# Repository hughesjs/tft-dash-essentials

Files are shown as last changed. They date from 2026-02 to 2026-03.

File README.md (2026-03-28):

# TFT Dash

A motorcycle dashboard replacement system. An Arduino-based interface board reads sensor signals from the bike — speed, RPM, coolant temperature, fuel level, battery voltage, indicators, and more — and streams data over USB serial to a Raspberry Pi, which renders a real-time graphical dashboard using SDL3.

## System Architecture

```
Phone App (BLE) ──> Arduino Firmware ──> USB Serial ──> Raspberry Pi Display
                    (ATMega32u4)          115200 bps     (SDL3, 1024x600)
                                                               |
                                                    TPMS Sensors (USB Serial)
```

The firmware outputs comma-delimited messages at 115200 bps. The display application deserialises these into dashboard state and renders at 60 fps. A separate TPMS receiver provides tyre pressure data via a second serial connection.

## Display Software Architecture

```
main.c (init, event loop, rendering)
  ├── draw.h          shared rendering state and drawing primitives (in progress)
  ├── dashboard_anims.h/c   animation instances and data tables
  │   └── animation.h/c     generic data-driven animation engine
  ├── sensor_feed.h/c       firmware serial data + comms staleness tracking
  ├── tpms_feed.h/c         tyre pressure serial data
  ├── parser.h/c             serial message deserialisation
  ├── assets.h/c             PNG texture management (stb_image)
  └── menu.h/c               menu screen data tables
```

Pure C23 codebase. Three threads: main (render + animation ticking), sensor feed (firmware serial), and TPMS feed (tyre pressure serial). 62 tests across 6 suites.

## Repository Structure

| Directory | Description |
|---|---|
| `display/` | Display application (C23/SDL3) for Raspberry Pi |
| `firmware/` | Arduino firmware for the sensor interface board (ATMega32u4) |
| `hardware/` | EAGLE schematic/board files for Gen4 PCB + 3D-printable enclosure STLs |
| `simulator/` | .NET/Avalonia desktop simulator for development without hardware |
| `buildroot-tftdash/` | Buildroot external tree for building the Pi SD card image |
| `docs/` | Protocol specs, signal reverse engineering notes, update system design |

## Quick Start

```bash
# Build the display application (requires Zig 0.15+)
make display

# Run all tests
make test

# Build the firmware (requires arduino-cli)
make firmware

# Build the simulator (requires .NET 10)
make simulator

# Full SD card image (firmware + display cross-compile + Buildroot)
make

# See all targets
make help
```

### Bike Model Selection

Uncomment one define at the top of `firmware/firmware.ino`:

- `#define BIKE_FZS1000` — Yamaha FZS1000 Fazer
- `#define BIKE_FZS600` — Yamaha FZS600 Fazer

This controls gear ratios, primary drive ratio, wheel diameter, and RPM calibration.

## Features

- Real-time speed, RPM, coolant temperature, battery voltage, and fuel level
- Gear position indicator (calculated from sprocket ratios)
- Turn indicator, high beam, neutral, and oil warning lights
- TPMS (tyre pressure monitoring) with two hardware variants
- Navigation overlay with turn-by-turn directions
- 9 colour themes with automatic day/night switching
- On-screen menu system for configuration
- NO COMMS warning when serial data goes stale
- Data-driven animation system (startup sequence, RPM effects, transitions)
- A/B rootfs update system for atomic SD card updates

## Documentation

See `docs/` for detailed documentation:

- **`SERIAL-PROTOCOL.md`** — Complete serial protocol specification
- **`signal-reverse-engineering.md`** — Electrical signal details and calibration constants
- **`ab-update-plan.md`** — A/B rootfs update system design
- **`ota-update-plan.md`** — Over-the-air WiFi update architecture (planned)

## Licence

2018-2025 TFTDashProject / Danny Draper.

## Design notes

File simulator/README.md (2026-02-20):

# TFT Dash Simulator

A cross-platform desktop simulator for the TFT Dash motorcycle dashboard system, built with Avalonia UI.

## Features

- **Modern Desktop UI**: Built with Avalonia 11.2 for native look and feel on Linux, macOS, and Windows
- **Dark Theme**: VS Code Dark+ colour scheme for comfortable viewing
- **Live Preview**: Real-time serial protocol message generation with parsed field display
- **Interactive Controls**: All 36 dashboard data fields editable via NumericUpDown and CheckBox controls
- **Preset Scenarios**: Quick-access buttons for common riding states (Idle, Cruising, High Speed, Low Fuel)
- **Keyboard Shortcuts**: F1-F4 for presets, Esc to exit
- **Pipe Output**: Optional FIFO pipe output at 10 Hz for integration with TFT Dash display software

## Building

```bash
dotnet build
```

## Running

Normal mode (GUI only):
```bash
dotnet run --project src/TftDashSimulator/TftDashSimulator.csproj
```

With pipe output (GUI + /tmp/tft-dash-pipe at 10 Hz):
```bash
dotnet run --project src/TftDashSimulator/TftDashSimulator.csproj -- --pipe
```

## Testing

```bash
dotnet test
```

## Project Structure

- `src/TftDashSimulator/` - Main application
  - `Core/` - Core logic and serial protocol handling (UI-agnostic)
  - `Views/` - Avalonia AXAML views (MainWindow, ControlsView, PreviewView)
  - `ViewModels/` - MVVM ViewModels
  - `Converters/` - Value converters for data binding
  - `Styles/` - Dark theme AXAML styles
- `tests/TftDashSimulator.Tests/` - Unit tests

## Architecture

The simulator uses the MVVM pattern:
- **DashboardState** (Model): Thread-safe state with INotifyPropertyChanged
- **MainViewModel**: Exposes DashboardState and preset commands
- **Views**: Avalonia UserControls with two-way data binding
- **MessageGenerator**: Converts DashboardState to TFT Dash serial protocol format
- **PipeWriter**: Background thread writing to FIFO pipe at 10 Hz (when --pipe flag is used)

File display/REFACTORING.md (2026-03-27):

# TFT Dash Refactoring Progress

## Completed

### Parser extraction
- Extracted message parsing from `testsdl.cpp` into `parser.h/c`
- Data-driven field descriptor tables instead of if-ladders
- Tokenisation via `strsep` (C23 + `_GNU_SOURCE`)
- Comprehensive test suite in `test_parser.c` (10 tests, all passing)
- `zig build test` to run

### Asset manager extraction
- Standalone `assets.h/c` module for themed BMP loading
- Two-key hash map lookup: `(theme, asset_name)` → `SDL_Texture*`
- FNV-1a hashing, open addressing with linear probing, auto-resize at 70% load
- `asset_store_load_theme()` scans directories via `opendir`/`readdir`
- Test suite in `test_assets.c` (7 tests, all passing)
- `zig build test` runs both parser and asset tests

### Asset store integration into testsdl.cpp
- Replaced 143 global variables (72 `SDL_Surface*` + 71 `SDL_Texture*`) with 2 (`g_assets` + `g_current_theme`)
- Deleted `load_surface()`, `load_surfaces()`, and `init_textures()` (~1000 lines of boilerplate)
- All 9 themes loaded upfront at startup — no per-switch disk I/O
- Theme switching is now a string assignment instead of full surface reload + texture recreation
- `tex("Name.bmp")` helper for current-theme lookups, `tex_from("theme", "Name.bmp")` for fixed-theme
- Default-only assets (odometer setup, theme arrows) use `tex_from("default", ...)`
- Per-theme thumbnails use `tex_from("green", "greenthumb.bmp")` etc.
- ~1250 lines deleted, ~40 lines added

### Drawing function deduplication
- Replaced 7 near-identical `draw_*_string()` functions (~270 lines) with one `draw_glyph_string()` renderer (~20 lines)
- Data-driven `glyph_font` struct captures all differences: texture name, sprite atlas coords, glyph character set, case-insensitive matching, inter-glyph spacing, whitespace handling, clipping, and per-glyph y-offsets
- 8 font descriptors defined as static const: `FONT_SMALL_GREY`, `FONT_SMALL_BLUE`, `FONT_MEDIUM`, `FONT_LARGE`, `FONT_NAV_LARGE`, `FONT_NAV_SMALL`, `FONT_NAV_DIGITS`
- All existing function names kept as one-line wrappers (86 call sites untouched)
- `draw_speed_digit` left as-is (renders to pre-positioned destination rects, not a flowing string)

### snake_case naming convention
- All functions, globals, locals, struct types and members converted to snake_case
- Constants remain UPPER_CASE (already correct)

### Zig build system
- Replaced manual g++ invocations with `build.zig`
- Builds main app, parser tests, and handles asset copying
- Cross-compilation support for aarch64

## Display-side refactoring opportunities

### Sensor feed extraction
- Extracted serial connection, byte framing, and message parsing into `sensor_feed.h/c`
- Opaque `sensor_feed` struct — consumers get `const` pointers, can't write state
- Replaced ~50 global variables with `dash->`, `menu->`, `nav->` struct field access
- Deleted ~1400 lines from testsdl.cpp: `connect_interface()`, `pollInterface()`, `unpack_message()`, `unpack_menu_message()`, `unpack_nav_message()`, `choice()`, `select()`, test scenario functions
- 9 integration tests via named pipes in `test_sensor_feed.c`
- testsdl.cpp reduced from ~4400 to ~3070 lines

### Next: further extractions
The same pattern can be applied to:

1. **Extract the menu system** — `draw_menu()` (~500 lines of nested ifs) takes explicit input/output.
2. **Extract TPMS** — small, self-contained, same pattern.
3. **What remains in testsdl.cpp** is `main()`, the render loop, and drawing helpers — a thin orchestrator.

### Smaller wins (do whenever convenient)

1. ~~**Texture loading boilerplate**~~ — **Done.** Replaced by asset store integration.

2. ~~**Theme descriptor table**~~ — **Done.** `THEME_NAMES[]` array + `theme_name_from_id()` replaces all `if (theme == X)` ladders.

3. ~~**Nav symbol lookup table**~~ — **Done.** Replaced 17 strcmp chains with `nav_symbol_entry` lookup table + `nav_icon` enum.

4. ~~**Warning badge priority**~~ — **Done.** Replaced nested if/else staircase with `resolve_warning()` lambda returning a `warning_badge` struct. Priority order is now a flat list of early-returns.

5. **Nav distance protocol** — The phone app sends yards AND miles as separate fields, and the display picks which to show based on `nav_yards <= 300`. This split of responsibility is daft — the phone app knows the distance, it should send one value and let the display format it. Requires a phone app + protocol change.

## Firmware architectural change (future option)

### Current state

The firmware handles both signal acquisition AND application logic:
- Reads sensors, averages, converts to meaningful units
- Manages the entire menu state machine (which menu, which digit being edited, cycling values)
- Stores all settings in EEPROM (theme, units, sprockets, fan temp, TPMS, etc.)
- Controls the fan relay
- Tracks odometer/trips and persists to EEPROM
- Manages RTC

The display just renders whatever state the firmware sends. The protocol is one-directional (firmware to display).

### Proposal: move menu logic to the display

Make the firmware a sensor bridge. It reads hardware, outputs values, and accepts setting commands from the display.

**Stays on firmware (hardware-dependent):**
- Sensor reading, averaging, signal processing
- Fan relay control (safety-critical — must work if display crashes)
- Odometer/trip persistence in EEPROM (SD card too fragile for frequent writes on a motorcycle)
- RTC read/write
- Speed correction (must happen before odometer accumulation)

**Moves to display:**
- Menu state machine and navigation
- Theme/unit preferences (become Pi-side config, possibly a file)
- All menu digit editing state (odo digits, time digits, speed correction digits)

**New protocol:**

```
Firmware -> Display (sensor data only):
  {,speed,rpm,coolant,batt,fuel,neutral,oil,highbeam,left,right,
   gear,ambient_temp,hour,minute,odo,trip1,trip2,oil_press,oil_temp,
   fan_state,button_option,button_select,}

Display -> Firmware (commands):
  CMD:RESET_TRIP1
  CMD:RESET_TRIP2
  CMD:SET_SPD_CORRECT:-2.5
  CMD:SET_TIME:14:23
  CMD:SET_SPROCKET_FRONT:15
  CMD:SET_SPROCKET_REAR:44
  CMD:SET_FAN_TEMP:95
  CMD:SET_FAN_MODE:2
  CMD:SET_GEAR_INTERVAL:200
  CMD:SAVE_ODO
```

**Benefits:**
- Firmware becomes much simpler — no menu state machine, no digit editor state
- Serial protocol shrinks — no more sending 6 odo digits, 4 time digits, etc.
- Adding/changing menus only requires display changes
- Display-only settings (theme, units) don't round-trip through the firmware
- Button events are raw — display decides what they mean in context

**Costs:**
- Bidirectional serial (trivial — `Serial.read()` on Arduino, `write()` on Pi)
- Settings persistence needs thought — EEPROM for hardware settings, file for display settings
- If display is down, buttons do nothing (but they're useless without a screen anyway)

**Implementation path:**
1. Add `Serial.read()` command handler to firmware
2. Strip menu state machine from firmware
3. Implement menu logic on display side
4. Simplify serial protocol
5. Add display-side config file for theme/units/layout

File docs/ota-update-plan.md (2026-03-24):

# OTA Update System — WiFi AP Mode

Design for wireless update delivery without USB sticks.

## Architecture

The Pi temporarily becomes a WiFi access point. A phone app connects and pushes the update directly. BLE (or a physical button combo) triggers update mode.

```
Phone App                    Arduino (BLE)              Pi
─────────                    ─────────────              ──
1. Tap "Update"
2. Send BLE ──────────────> Relay ──────────────> Start hostapd AP
   "START_UPDATE"                                  "TFTDash" network
                                                   Start HTTP server
                                                   on 192.168.4.1:8080

3. Join "TFTDash" network
   (iOS: NEHotspotConfiguration
    with system dialog)

4. POST update zip ─────── WiFi direct to Pi ───> Receive, extract,
   to 192.168.4.1:8080                            apply update

5. Pi responds 200 OK ──── WiFi ────────────────> Tear down AP
                                                   Restart dash
6. Phone auto-rejoins
   previous network
```

## Why This Approach

### BLE alone is too slow
The update package is ~10MB zipped, 330MB uncompressed. BLE tops out at 10-30 KB/s. Even the compressed package would take 5-15 minutes. The full BMP set uncompressed would take hours. The ATMega32u4 only has 2.5KB of RAM — it can't buffer or relay large transfers.

### Pi as AP avoids phone hotspot dependency
iOS has no public API to enable Personal Hotspot programmatically (`NEHotspotConfiguration` only joins existing networks, it can't create one). A Pi-hosted AP works identically on iOS and Android with no manual steps.

### Fixed known IP
The Pi is always 192.168.4.1 as the AP gateway. No mDNS discovery, no DHCP lease parsing, no platform-specific gateway addresses.

### BLE only carries control messages
"Start update mode" and "disconnect" — tiny messages that the existing BLE relay through the Arduino handles already. No new BLE protocol needed.

## Implementation Plan

### 1. Pi-Side Update Daemon

A small service/script that:

1. **Listens for update trigger** — either:
   - BLE command relayed via serial (watches for `<UPD:START%>` in the serial stream)
   - Physical button combo (hold option + select for 5 seconds) for garage use without a phone
2. **Starts WiFi AP** — `hostapd` + `dnsmasq` to create "TFTDash" network on 192.168.4.1
3. **Runs HTTP server** on port 8080 accepting POST to `/update`
4. **Receives and applies update** — validate zip, extract to staging area, copy binary + assets into place, optionally flash firmware hex via avrdude
5. **Tears down AP** and restarts the dashboard

Could be ~50 lines of bash wrapping a small HTTP receiver (e.g. Python one-liner or a tiny C program).

### 2. Firmware Changes

- New BLE message type: `<UPD:START%>` to trigger update mode
- Arduino relays to Pi via existing serial passthrough — the firmware already passes all BLE messages through, so this may need no firmware changes at all beyond the phone app sending the right string

### 3. Phone App

- "Update Dash" button that bundles the current update zip
- Sends BLE `START_UPDATE` command to the Arduino
- Uses `NEHotspotConfiguration` (iOS) / standard WiFi API (Android) to join "TFTDash" network — iOS shows one system confirmation dialog
- POSTs zip to `http://192.168.4.1:8080/update`
- Shows progress bar during upload
- Handles success/failure response from Pi
- On completion, phone auto-rejoins its previous network

### 4. Pi Requirements

- `hostapd` and `dnsmasq` packages installed on the Pi SD card image
- WiFi hardware (Pi 3 has built-in, but it is **currently disabled** via `dtoverlay=pi3-disable-wifi` in `/boot/config.txt` — this needs removed)
- Bluetooth is also disabled (`dtoverlay=pi3-disable-bt`) — can stay disabled since BLE goes through the Arduino, not the Pi
- Pre-configured `hostapd.conf` for the "TFTDash" AP
- The update daemon installed as a systemd service or integrated into `updatetft.sh`
- Root filesystem is read-only — daemon must remount rw before applying updates (existing script already does this)

## Current Update Mechanism (USB A/B)

The A/B rootfs update system handles USB-based updates — see `docs/ab-update-plan.md`. OTA via WiFi AP would be an additional delivery path using the same rootfs image format.

## TODO

- [ ] Implement Pi-side update daemon (hostapd AP + HTTP receiver)
- [ ] Add `<UPD:START%>` BLE message handling (may be zero firmware work)
- [ ] Phone app: BLE trigger + WiFi join + HTTP upload

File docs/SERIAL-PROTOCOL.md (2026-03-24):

# TFT Dash Serial Protocol

This document describes the serial communication protocols used by the TFT Dash system. There are three independent serial interfaces:

1. **Main interface** - Firmware to Display (USB serial)
2. **TPMS interface** - Tyre Pressure Monitoring System sensors to Display (separate USB serial)
3. **Navigation interface** - Phone to Firmware via BLE module on the Arduino (passed through to the Display embedded in the main interface output)

---

## 1. Main Interface (Firmware to Display)

**Connection:** USB serial over `/dev/ttyACM0` or `/dev/ttyACM1` (Linux) / `/dev/cu.usbmodem*` or `/dev/cu.usbserial-*` (macOS)

**Baud rate:** 115200

**Serial config:** 8N1, no flow control

**Direction:** Firmware sends continuously; display receives and parses.

The firmware outputs one of two message types on each loop iteration, depending on whether the user is in the main dashboard view or navigating the on-screen menu.

### 1.1 Live Data Message

Sent when the dashboard is in normal (non-menu) mode. Contains real-time sensor readings.

**Format:** `{,field1,field2,...,fieldN,}`

- Starts with `{`
- Fields are comma-delimited
- Ends with `}`
- Valid messages are between 90 and 400 characters in length

| Field index | Field | Type | Description |
|---|---|---|---|
| 0 | `{` | char | Start marker |
| 1 | speed | unsigned int | Current speed (in user's chosen unit: MPH or KM/H) |
| 2 | rpm | unsigned int | Engine RPM |
| 3 | coolant | int | Coolant temperature (averaged) |
| 4 | battery | float | Battery voltage (e.g. `12.5`) |
| 5 | hour | int | Current hour (0-23) from RTC |
| 6 | minute | int | Current minute (0-59) from RTC |
| 7 | fuel | int | Fuel float sensor value (raw integer) |
| 8 | neutral | int | Neutral light (1 = engaged, 0 = off) |
| 9 | oil | int | Oil level warning (1 = warning, 0 = ok) |
| 10 | highbeam | int | High beam indicator (1 = on, 0 = off) |
| 11 | left | int | Left indicator (1 = on, 0 = off) |
| 12 | right | int | Right indicator (1 = on, 0 = off) |
| 13 | menustate | int | Current menu state (`menulevel + choicestate`; 0 = main dashboard) |
| 14 | infomode | int | Info panel display mode |
| 15 | trip1 | float | Trip 1 distance (in user's chosen unit) |
| 16 | trip2 | float | Trip 2 distance (in user's chosen unit) |
| 17 | odo | float | Odometer reading (in user's chosen unit) |
| 18 | km | int | Unit mode (1 = kilometres, 0 = miles) |
| 19 | speedcorrection | float | Speed correction factor |
| 20 | theme | int | Current display theme ID |
| 21 | ambient | int | Ambient temperature (averaged) |
| 22 | gear | int | Current gear (calculated from sprocket ratios) |
| 23 | mpg | int | Miles per gallon |
| 24 | range | int | Estimated range remaining |
| 25 | maxspeed | unsigned int | Maximum speed recorded this trip (in user's chosen unit) |
| 26 | triptimehour | int | Trip time hours |
| 27 | triptimemin | int | Trip time minutes |
| 28 | oilpressavail | int | Oil pressure hardware available (1 = yes, 0 = no). Always 0 on Gen4 boards. |
| 29 | oilpress | int | Oil pressure sensor reading (averaged). Always 0 on Gen4 boards. |
| 30 | oiltemp | int | Oil temperature sensor reading (averaged). Always 0 on Gen4 boards. |
| 31 | fahrenheit | int | Temperature unit (1 = Fahrenheit, 0 = Celsius) |
| 32 | bar | int | Pressure unit (1 = Bar, 0 = PSI) |
| 33 | frontsensor | int | TPMS front sensor ID |
| 34 | rearsensor | int | TPMS rear sensor ID |
| 35 | frontpressurelow | int | Front tyre low pressure threshold |
| 36 | rearpressurelow | int | Rear tyre low pressure threshold |
| 37 | nav | string | Navigation message from phone via BLE (see section 3). Empty if no navigation active. |
| *end* | `}` | char | End marker |

**Example:**
```
{,78,5200,89,12.5,14,35,477,0,1,0,0,0,0,0,12.5,24.8,1234.5,0,1.0,3,22,4,45,120,78,1,35,0,0,0,0,0,1,2,30,28,,}
```

### 1.2 Menu Data Message

Sent when the user is navigating the on-screen menu system (i.e. `menulevel + choicestate != 0`). Contains current menu state and all configurable settings.

**Format:** `[,field1,field2,...,fieldN,]`

- Starts with `[`
- Fields are comma-delimited
- Ends with `]`
- Valid messages are between 80 and 100 characters in length

| Field index | Field | Type | Description |
|---|---|---|---|
| 0 | `[` | char | Start marker |
| 1 | menustate | int | Current menu state (`menulevel + choicestate`) |
| 2 | ododigit1 | int | Odometer setup digit 1 |
| 3 | ododigit2 | int | Odometer setup digit 2 |
| 4 | ododigit3 | int | Odometer setup digit 3 |
| 5 | ododigit4 | int | Odometer setup digit 4 |
| 6 | ododigit5 | int | Odometer setup digit 5 |
| 7 | ododigit6 | int | Odometer setup digit 6 |
| 8 | odo2digit1 | int | Odometer confirmation digit 1 |
| 9 | odo2digit2 | int | Odometer confirmation digit 2 |
| 10 | odo2digit3 | int | Odometer confirmation digit 3 |
| 11 | odo2digit4 | int | Odometer confirmation digit 4 |
| 12 | odo2digit5 | int | Odometer confirmation digit 5 |
| 13 | odo2digit6 | int | Odometer confirmation digit 6 |
| 14 | odoerror | int | Odometer error state |
| 15 | settimedigit0 | int | Set time digit 0 (tens of hours) |
| 16 | settimedigit1 | int | Set time digit 1 (units of hours) |
| 17 | settimedigit2 | int | Set time digit 2 (tens of minutes) |
| 18 | settimedigit3 | int | Set time digit 3 (units of minutes) |
| 19 | spcdigit0 | int | Speed correction sign/digit 0 (+ or -) |
| 20 | spcdigit1 | int | Speed correction digit 1 |
| 21 | spcdigit2 | int | Speed correction digit 2 |
| 22 | spcdigit3 | int | Speed correction digit 3 |
| 23 | frontsprocket | int | Front sprocket tooth count |
| 24 | rearsprocket | int | Rear sprocket tooth count |
| 25 | coolantfantemp | int | Coolant fan activation temperature |
| 26 | km | int | Using kilometres (1 = km, 0 = miles) |
| 27 | fh | int | Using Fahrenheit (1 = Fahrenheit, 0 = Celsius) |
| 28 | bar | int | Using Bar (1 = Bar, 0 = PSI) |
| 29 | frontsensor | int | TPMS front sensor ID |
| 30 | rearsensor | int | TPMS rear sensor ID |
| 31 | frontpressurelow | int | Front tyre low pressure threshold |
| 32 | rearpressurelow | int | Rear tyre low pressure threshold |
| 33 | controllayout | int | Control button layout |
| 34 | daytheme | int | Day theme ID |
| 35 | nighttheme | int | Night theme ID |
| 36 | currentlightlevel | int | Current ambient light sensor reading |
| 37 | lightswitchvalue | int | Light level threshold for day/night switching |
| 38 | fanneutraloption | int | Fan neutral mode option in coolant fan setup |
| 39 | gearratiointerval | int | Gear ratio update interval setting |
| *end* | `]` | char | End marker |

### 1.3 Menu State Constants

Menu states are encoded as `menulevel + choicestate`. The major menu category is a single digit, and sub-options are encoded as `category * 100 + offset`:

| Constant | Value | Description |
|---|---|---|
| `MAINDASHBOARD` | 0 | Normal dashboard view (live data sent) |
| `RESETTRIP1` | 1 | Reset Trip 1 |
| `RESETTRIP2` | 2 | Reset Trip 2 |
| `CONTROLSETUP` | 3 | Control layout setup |
| `CONTROLLAYOUT1` | 301 | Control layout option 1 |
| `CONTROLLAYOUT2` | 302 | Control layout option 2 |
| `SETUNITS` | 4 | Unit selection menu |
| `SETUNITSMILES` | 401 | Select miles |
| `SETUNITSKM` | 402 | Select kilometres |
| `SETUNITSCELCIUS` | 403 | Select Celsius |
| `SETUNITSFARENHEIT` | 404 | Select Fahrenheit |
| `SETUNITSPSI` | 405 | Select PSI |
| `SETUNITSBAR` | 406 | Select Bar |
| `SETTIME` | 5 | Set time menu |
| `SETTIMEDIGIT1-4` | 501-504 | Individual time digits |
| `AMBIENTLIGHTSETUP` | 6 | Ambient light setup |
| `DAYTHEMEPLUS/MINUS` | 601-602 | Day theme selection |
| `NIGHTTHEMEPLUS/MINUS` | 603-604 | Night theme selection |
| `LIGHTLEVELPLUS/MINUS` | 605-606 | Light level threshold |
| `SPEEDCORRECTIONMENU` | 7 | Speed correction |
| `SETDISPLAYTHEME` | 8 | Theme selection |
| `GEARINDICATORSETUP` | 9 | Gear indicator / sprocket setup |
| `COOLANTFANSETUP` | 10 | Coolant fan temperature setup |
| `TPMSSETUP` | 11 | TPMS sensor configuration |
| `ODOSETUP` | 12 | Odometer setup |

### 1.4 Display Theme IDs

| Value | Theme |
|---|---|
| 0 | Default (white) |
| 1 | Green |
| 2 | Red |
| 3 | Blue |
| 4 | Orange |
| 5 | Yellow |
| 6 | High contrast white |
| 7 | Night |
| 8 | High contrast dark |

### 1.5 Message Framing

The display reads the serial stream byte-by-byte on a background thread. Messages are framed as follows:

1. When a `{` or `[` character is received, the read buffer is reset and accumulation begins from that character.
2. Bytes are accumulated until the next start marker is received.
3. Before parsing, the message is validated:
   - Live data (`{`): length must be > 90 and < 400 characters
   - Menu data (`[`): length must be > 80 and < 100 characters
4. If validation passes, the message is copied to a global buffer and the appropriate unpack function is called.

On disconnection (0 or fewer bytes read), the display closes and reopens the serial port automatically.

---

## 2. TPMS Interface (Tyre Pressure Monitoring)

The TPMS system uses a **separate USB serial connection** between a wireless TPMS receiver and the Raspberry Pi. This is independent of the main firmware serial link - the TPMS receiver connects directly to the Pi, not via the Arduino. Two hardware variants are supported.

**Connection:** `/dev/ttyUSB0` or `/dev/ttyUSB1` (Linux) / `/dev/cu.usbserial-*` (macOS)

**Direction:** TPMS receiver sends binary data; display receives and parses on a dedicated thread.

### 2.1 Standard TPMS

**Baud rate:** 9600

**Serial config:** 8N1, no flow control

**Frame format:** Binary, 14 bytes per frame

| Byte | Value | Description |
|---|---|---|
| 0 | `0xAA` (170 / -86 signed) | Header byte 1 |
| 1 | `0xA1` (161 / -95 signed) | Header byte 2 |
| 2 | `0x41` (65) | Header byte 3 |
| 3 | 14 | Packet length |
| 4 | 99 | Mode/check byte |
| 5 | 1-4 | Sensor number (1-4) |
| 6-8 | — | Unknown / ID bytes |
| 9 | pressure high | Tyre pressure byte 1 (high bits) |
| 10 | pressure low | Tyre pressure byte 2 (low bits) |
| 11 | temperature | Temperature byte |
| 12 | state | Warning state byte |
| 13 | — | Unknown |

**Framing:** Messages start when byte `0xAA` is followed by `0xA1`. Valid frames are > 13 bytes.

**Pressure calculation:**
```
bar = 0.025 * (((byte9 & 3) * 256) + (byte10 & 255))
psi = bar * 14.5
```

**Temperature calculation:**
```
celsius = (byte11 & 255) - 50
```

**Warning state (byte 12):**

| Condition | Test |
|---|---|
| Fast leak | `(byte12 & 3) == 1` |
| High pressure | `(byte12 & 16) == 16` |
| Low pressure | `(byte12 & 8) == 8` |
| High temperature | `(byte12 & 4) == 4` |
| Low battery | `(byte12 & 128) == 128` |
| Normal | None of the above |

### 2.2 eBay TPMS (Budget Alternative)

**Baud rate:** 19200

**Serial config:** 8N1, no flow control

**Frame format:** Binary, 8 bytes per frame

| Byte | Value | Description |
|---|---|---|
| 0 | `0x55` (85) | Header byte 1 |
| 1 | `0xAA` (170 / -86 signed) | Header byte 2 |
| 2 | 8 | Packet length |
| 3 | sensor position | Sensor position code |
| 4 | pressure | Tyre pressure byte |
| 5 | temperature | Temperature byte |
| 6 | state | Warning state byte |
| 7 | — | Unknown |

**Framing:** Messages start when byte `0x55` (85) is followed by `0xAA` (-86 signed). Valid frames are > 5 bytes.

**Sensor position mapping:**

| Raw value | Mapped sensor | Position |
|---|---|---|
| 0 | 1 | Left front |
| 1 | 2 | Right front |
| 16 | 3 | Back left |
| 17 | 4 | Back right |

**Pressure calculation:**
```
psi = (byte4 & 255) * 3.44
bar = psi / 14.5
```

**Temperature calculation:**
```
celsius = (byte5 & 255) - 50
```

**Warning state (byte 6):**

| Condition | Test |
|---|---|
| No signal | `(byte6 & 32) != 0` |
| Air leak | `(byte6 & 8) != 0` |

### 2.3 Sensor Assignment

The TPMS front and rear sensor IDs are configurable through the on-screen menu system. The display matches incoming sensor numbers against `frontsensorid` and `rearsensorid` to assign readings to the front and rear tyre displays.

---

## 3. Navigation Messages (Phone via BLE through Arduino)

Navigation data originates from a phone app and is received by a Bluetooth Low Energy module connected to the **Arduino board** (not the Pi) via SoftwareSerial at 9600 baud.

The Arduino buffers incoming BLE bytes in its main loop. Once a complete navigation message is received (terminated by `%>`), the firmware stores it and includes it as field 37 of the next live data message sent over USB to the Raspberry Pi. The Pi never communicates with the BLE module directly.

### 3.1 BLE to Firmware Framing

The phone sends navigation messages terminated by the two-character sequence `%>`. The firmware accumulates bytes until it sees this terminator, at which point the complete message is stored in the `szNav` buffer. If no navigation message has been received, field 37 of the live data output is empty.

### 3.2 Navigation Message Format

Within the live data message, the navigation string uses `%` as its own field delimiter (distinct from the comma delimiter used in the surrounding protocol).

**Format:** `%symbol%road%towards%exit%yards%miles%drivingleft%destdistance%`

| Field index | Field | Type | Description |
|---|---|---|---|
| 1 | symbol | string | Navigation manoeuvre symbol code (see table below) |
| 2 | road | string | Road name to turn onto |
| 3 | towards | string | Place name being headed towards |
| 4 | exit | string | Motorway exit number (if applicable) |
| 5 | yards | int | Distance to next manoeuvre in yards |
| 6 | miles | float | Distance to next manoeuvre in miles |
| 7 | drivingleft | int | Driving side (1 = left-hand traffic / UK, 0 = right-hand traffic) |
| 8 | destdistance | float | Total distance to destination in miles |

### 3.3 Navigation Symbol Codes

| Code | Description |
|---|---|
| `MUT` | Make a U-turn (icon flipped based on driving side) |
| `MEX` | Motorway exit (icon flipped based on driving side) |
| `TNR` | Turn right |
| `TNL` | Turn left |
| `SLL` | Slight left |
| `SLR` | Slight right |
| `RB1` | Roundabout, 1st exit (icon flipped based on driving side) |
| `RB2` | Roundabout, 2nd exit (icon flipped based on driving side) |
| `RB3` | Roundabout, 3rd exit (icon flipped based on driving side) |
| `RB4` | Roundabout, 4th exit (icon flipped based on driving side) |
| `RB5` | Roundabout, 5th exit (icon flipped based on driving side) |
| `LNR` | Keep right / lane right |
| `LNL` | Keep left / lane left |
| `CON` | Continue straight |
| `ARV` | Arrived at destination |
| `PRK` | Parking |
| `FRY` | Ferry |

**Note:** Symbols marked "flipped based on driving side" render a mirrored icon depending on the `drivingleft` field, to correctly show the manoeuvre for left-hand or right-hand traffic countries.

### 3.4 Unit Conversion on Display

The display automatically converts navigation distances based on the user's unit preference:
- **Yards to metres:** `metres = yards / 1.094`
- **Miles to kilometres:** `km = miles * 1.609`

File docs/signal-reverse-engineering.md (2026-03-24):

# TFT Dash — Motorcycle Signal Reverse Engineering

This document describes the electrical signals read by the TFT Dash firmware from the motorcycle's wiring loom. Originally reverse-engineered from the firmware written for a **Yamaha FZS1000 Fazer**, with notes on differences for the **FZS600 Fazer**.

## Signal Overview

| Signal | Pin | Type | Summary |
|---|---|---|---|
| Speed | 0 | Frequency (interrupt) | Pulse-width measurement from speed sensor |
| RPM | 1 | Frequency (interrupt) | Pulse-width measurement from ignition |
| Coolant Temp | A3 | Analogue (thermistor) | NTC via 2kΩ voltage divider |
| Ambient Temp | A0 | Analogue (thermistor) | NTC via 2kΩ voltage divider |
| Fuel Level | A2 | Analogue (float) | Resistive float, raw ADC |
| Battery Voltage | A4 | Analogue (divider) | 10kΩ + 5.09kΩ voltage divider |
| Light Sensor | A1 | Analogue (LDR) | Raw ADC, 0=dark 1023=bright |
| Neutral | 5 | Digital | LOW = neutral |
| Oil Level | 4 | Digital | HIGH = warning |
| High Beam | 9 | Digital | HIGH = on |
| Left Indicator | 10 | Digital | HIGH = on |
| Right Indicator | 11 | Digital | HIGH = on |
| Option Button | 8 | Digital | HIGH = pressed, 150ms debounce |
| Select Button | 7 | Digital | HIGH = pressed, 150ms debounce |
| Fan Relay | 12 | Digital OUTPUT | HIGH = fan on |

---

## Frequency-Based Signals

### Speed Sensor

The speed signal comes from the front wheel speed sensor (or gearbox-driven sensor depending on model). It produces a pulsed signal whose frequency is proportional to road speed.

**Interrupt configuration:** Triggers on `CHANGE` (both rising and falling edges), but the ISR only measures on the **falling edge** after seeing a rising edge — so it captures the full period of one complete pulse cycle.

**Valid pulse width range:** 300–60,000 µs. Anything outside this is treated as 0 speed. If no interrupt fires for >1 second, speed is set to 0.

**Conversion formula:**
```
pulses_per_second = 1,000,000 / pulse_width_µs
speed_m_s = pulses_per_second / 40.3
speed_mph = speed_m_s × 2.23694
```

**Calibration constant:** 40.3 pulses per metre (empirically determined for FZS1000).

**Smoothing pipeline:**
1. Raw pulse width captured by ISR
2. Only valid if bike out of neutral for >1.5 seconds
3. Configurable ± percentage speed correction applied
4. Floating average updated every 30ms
5. Final average over 20 samples

### RPM (Tachometer)

The RPM signal comes from the ignition system. Both the FZS600 and FZS1000 use **wasted-spark ignition with 2 coil packs** (cylinders 1&4 and 2&3), producing **2 ignition pulses per crankshaft revolution**.

**Interrupt configuration:** Same as speed — triggers on `CHANGE`, but only measures on the falling edge after a rising edge. Captures the full period of one pulse cycle.

**Valid pulse width range:** 1,500–30,000 µs. If no interrupt for >1 second, RPM is set to 0.

**Conversion formula:**
```
pulses_per_second = 1,000,000 / pulse_width_µs
rpm = pulses_per_second × RPM_CONSTANT
```

**RPM constant:** The firmware uses `29.60`, which was adjusted down from an original `33.3`. The theoretical value for 2 pulses/rev measured period-to-period is `60 / 2 = 30`, so 29.60 is close but was empirically tuned. The comment in the code is self-contradictory — it states 33.3 "was correct" but then uses 29.60.

**Smoothing pipeline:**
1. Raw pulse width captured by ISR
2. Averaged over 20 consecutive pulses in the ISR itself
3. Floating average with variable step rates (updated every 10ms):
   - ≥3000 RPM difference → step 1000
   - ≥2000 → step 500
   - ≥1000 → step 100
   - ≥500 → step 10
   - ≥250 → step 5
   - Otherwise → step 1
4. Final average over 20 samples (used for gear calculation)

**Engine running threshold:** >500 RPM averaged. Engine considered "running for 10 seconds" flag used for fan control timing.

---

## Analogue Signals

### Coolant Temperature

**Circuit:** NTC thermistor connected through a voltage divider with **R1 = 2,000Ω** (upper resistor) and **Vin = 5.1V** reference.

**Resistance measurement:**
```
Vout = (ADC_reading × 5.1) / 1023
R_thermistor = 2000 × ((5.1 / Vout) - 1)
```

**Temperature conversion (simplified Steinhart-Hart / Beta equation):**
```
t = ln(R_measured / R_stock)
T = 1 / ((1/298.15) + (t / beta)) - 273.15  →  °C
```

| Parameter | FZS1000 Value |
|---|---|
| R_stock | 30,000 Ω |
| Beta | 4,000 |

**Read interval:** Every 1 second. Averaged over 70 samples.

### Ambient / Air Temperature

Same voltage divider circuit as coolant (R1 = 2,000Ω, Vin = 5.1V). Different thermistor characteristics:

| Parameter | Value |
|---|---|
| R_stock | 10,000 Ω |
| Beta | 3,750 |

**Averaging:** 170 samples (longer window for stability since ambient changes slowly).

### Fuel Level

**Circuit:** Resistive fuel tank float sensor read as raw ADC (0–1023). Not converted to resistance — the ADC value is used directly.

**Smoothing:** Averaged over 70 samples, then a floating value that tracks ±1 per 2 seconds to prevent gauge flickering.

**Conversion to litres:** Piecewise-linear lookup table based on observed float characteristics for the FZS1000 tank (approximately 21 litres capacity). The non-linear mapping compensates for tank geometry:

| ADC Range | Litres (approx.) |
|---|---|
| 0–93 | 21 → 20 |
| 93–121 | 20 → 19 |
| 121–148 | 18 → 17 |
| 148–180 | 17 → 16 |
| 180–211 | 15 → 14 |
| 211–241 | 14 → 13 |
| 241–281 | 12 → 10 |
| 281–320 | 10 → 9 |
| 320–367 | 9 → 7 |
| 367–426 | 7 → 6 |
| 426–481 | 6 → 5 |
| 481–506 | 5 → 4 |

**Note:** This lookup table is specific to the FZS1000 tank shape and float mechanism. It will need recalibration for any other tank.

**Refuel detection:** A jump of >2 litres triggers a refuel event which resets MPG calculation.

### Battery Voltage

**Circuit:** Voltage divider with **10kΩ + 5.09kΩ** resistors stepping down the 12V battery to ADC-safe levels.

**Conversion:**
```
Vout = ADC_reading × 0.0074
V_battery = Vout × (10000 + 5090) / 5090
V_battery = Vout × 2.9685
```

**Read interval:** Every 1 second. Averaged over 70 samples.

### Light Sensor

**Circuit:** Raw analogue reading from an LDR or photodiode. 0 = dark, 1023 = bright.

**Read interval:** Every 500ms.

**Usage:** Compared against a configurable threshold (`lightswitchvalue`, range 0–900) with 20-unit hysteresis band for automatic day/night theme switching.

---

## Digital Signals

| Signal | Active State | Notes |
|---|---|---|
| **Neutral** | LOW = in neutral | Pull-down. A 1.5-second delay after leaving neutral before speed readings are accepted (prevents erroneous readings during gear changes). |
| **Oil Level Warning** | HIGH = oil low | LOW = oil level OK. |
| **High Beam** | HIGH = on | Standard active-high from headlight relay. |
| **Left Indicator** | HIGH = on | Flashing signal from indicator relay. |
| **Right Indicator** | HIGH = on | Flashing signal from indicator relay. |
| **Option Button** | HIGH = pressed | 150ms debounce. 7-second hold triggers odometer setup. |
| **Select Button** | HIGH = pressed | 150ms debounce. Confirms menu selections. |

### Fan Relay (Output)

Digital output driving a relay for an aftermarket coolant fan. HIGH = fan on. Four configurable activation modes when in neutral:

1. **Always** — Whenever in neutral with engine running >10s
2. **After 1 minute** — After being in neutral for >60s
3. **Above 50°C** — In neutral with coolant ≥50°C
4. **Throttle blip** — RPM >2,500 in neutral

Additionally, the fan **always activates** when coolant temperature exceeds a configurable threshold (range 70–120°C, default 100°C), regardless of neutral state.

---

## Calculated / Derived Values

### Gear Detection

Uses RPM/speed ratio compared against a lookup table of theoretical ratios for each gear. The theoretical speed for a given RPM and gear is:

```
shaft_speed = rpm / primary_drive_ratio
wheel_speed = shaft_speed / gearbox_ratio / final_drive_ratio
road_speed = wheel_speed × π × wheel_diameter × 60 / 1609.344  (mph)
```

A floating average tracks the current ratio with hysteresis to prevent flickering between gears. The closest match from gears 1–6 is selected.

### Trip / Odometer

Accumulated from speed × time: `distance += (speed / 3600) × time_interval_ms`. Saves to EEPROM when increment ≥ 0.1 miles.

### Fuel Economy (MPG)

```
mpg = (distance_since_refuel / litres_consumed) × 4.546
range = (mpg / 4.546) × litres_remaining
```

Uses imperial gallons (4.546 litres).

---

## Bike-Specific Constants

### FZS1000 Fazer (original firmware values)

| Parameter | Value | Source |
|---|---|---|
| Speed: pulses per metre | 40.3 | Empirical |
| RPM constant | 29.60 | Empirical (theoretical: 30) |
| Primary drive ratio | 1.581 (68/43) | Service manual |
| 1st gear | 2.500 (35/14) | Service manual |
| 2nd gear | 1.842 (35/19) | Service manual |
| 3rd gear | 1.500 (30/20) | Service manual |
| 4th gear | 1.333 (28/21) | Service manual |
| 5th gear | 1.200 (30/25) | Service manual |
| 6th gear | 1.115 (29/26) | Service manual |
| Final drive (stock) | 2.750 (44/16) | Service manual |
| Wheel diameter | 0.629m | 180/55 ZR17 rear tyre |
| Fuel tank | ~21 litres | Empirical lookup table |

### FZS600 Fazer (corrected values)

| Parameter | Value | Source |
|---|---|---|
| Speed: pulses per metre | 40.3 (TBC) | Likely similar — needs verification |
| RPM constant | 29.60 (TBC) | Same 2-coil wasted spark — may need recalibration |
| Primary drive ratio | 1.708 (82/48) | Service manual |
| 1st gear | 2.846 (37/13) | Service manual |
| 2nd gear | 1.947 (37/19) | Service manual |
| 3rd gear | 1.545 (34/22) | Service manual |
| 4th gear | 1.333 (28/21) | Service manual |
| 5th gear | 1.190 (25/21) | Service manual |
| 6th gear | 1.074 (29/27) | Service manual |
| Final drive (stock) | 3.200 (48/15) | Service manual |
| Wheel diameter | 0.624m | 160/60 ZR17 rear tyre |
| Fuel tank | ~19.4 litres | Service manual (lookup table needs recalibration) |

---

## Serial Output Protocol

### Live Data Frame

Framed by `{` and `}`, comma-delimited:
```
{,speed,rpm,coolant,battery,hour,minute,fuel,neutral,oil,highbeam,left,right,menu,info,trip1,trip2,odo,km_flag,speed_correction,theme,ambient,gear,mpg,range,maxspeed,triptime_hour,triptime_min,[oilpress_avail,oilpress,oiltemp,]fh,bar,frontsensor,rearsensor,frontpressurelow,rearpressurelow,nav_data,}
```

### Menu Data Frame

Framed by `[` and `]`, comma-delimited:
```
[,menustate,odo_digits(1-6),odo_check(1-6),time_digits(0-3),speed_correction_digits,front_sprocket,rear_sprocket,coolant_fan_temp,km,fh,bar,front_sensor,rear_sensor,front_pressure_low,rear_pressure_low,control_layout,day_theme,night_theme,light_level,light_threshold,fan_neutral_option,gear_ratio_interval,]
```

Both are sent continuously at 115200 bps over USB serial.

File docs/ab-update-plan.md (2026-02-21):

# A/B Rootfs Update Plan

**Status: Implemented** — see `buildroot-tftdash/` for the actual code.

## Overview

The TFT Dash Buildroot image uses an A/B rootfs partition scheme for atomic updates. Updates are delivered via USB stick — the entire Buildroot rootfs image is `dd`'d onto the standby partition, the boot target is flipped in `cmdline.txt`, and the device reboots.

This preserves the core benefit of Buildroot: the image produced by `build.sh` is the single source of truth for what runs on the dash. No patching individual files, no drift.

## SD Card Partition Layout

```
mmcblk0p1  boot      32MB    FAT32   (kernel, DTBs, config.txt, cmdline.txt)
mmcblk0p2  rootfs_a  512MB   ext4    (active — complete Buildroot rootfs, read-only)
mmcblk0p3  rootfs_b  512MB   ext4    (standby — dd target for updates)
mmcblk0p4  data      16MB    ext4    (persistent rw partition — update log, future use)
```

- **boot**: Kernel, device tree, Pi firmware blobs, and boot config. Rarely changes.
- **rootfs_a / rootfs_b**: Identical in size. One is active (mounted as `/`), the other is the update target. Both are full Buildroot images containing the app binary, BMP assets, libraries, everything.
- **data**: Small persistent partition mounted at `/data`. Currently used for update logging. User settings (odometer, trip, theme, etc.) are stored on the Arduino's I2C EEPROM, not on the Pi.

Total: ~1.1GB. Fits easily on any SD card (typical is 8-32GB). Both rootfs slots get the same image on initial flash, so either is bootable from the start.

## Design Decisions

- **cmdline.txt swap** (no U-Boot) — simple, appropriate for a physically-accessible motorbike dash. The update script rewrites `root=` in `cmdline.txt` to point at the standby partition.
- **No udev** — the system uses devtmpfs. USB detection uses a boot-time scan (`S10usbupdate` init script) instead of udev rules.
- **No root entry in fstab** — the kernel mounts root via the `root=` cmdline parameter. This avoids hardcoding which slot is active.
- **Boot partition stays 32MB** — current contents total ~27MB.
- **Rootfs partitions: 512MB each** — matches the existing Buildroot rootfs size.

## Update Flow

1. User builds a new image (`make image`)
2. User creates an update package (`make update-package`)
3. User copies `tftupdate/` directory to a FAT32 USB stick
4. User plugs USB into the Pi and reboots (or powers on)
5. `S10usbupdate` init script (runs at boot before the dashboard) scans USB devices
6. If `tftupdate/rootfs.img` is found, it hands off to `tft-update.sh`
7. `tft-update.sh`: verifies SHA-256 checksum, `dd`s image to standby partition, flips `cmdline.txt`, optionally flashes Arduino firmware, reboots
8. Device boots into the new rootfs slot

## Key Files

| File | Purpose |
|---|---|
| `buildroot-tftdash/board/genimage.cfg` | 4-partition SD card layout |
| `buildroot-tftdash/overlay/etc/fstab` | A/B-aware mounts (no root entry, /data on p4) |
| `buildroot-tftdash/overlay/usr/bin/tft-update.sh` | Core update script |
| `buildroot-tftdash/overlay/etc/init.d/S10usbupdate` | Boot-time USB scan |
| `buildroot-tftdash/board/post-image.sh` | Generates cmdline.txt (defaults to slot A) |

## USB Update Package Format

Built via `make update-package` (or `buildroot-tftdash/build.sh update-package`):

```
tftupdate/
├── rootfs.img            Full ext4 rootfs image (dd'd to standby partition)
├── rootfs.img.sha256     SHA-256 checksum
└── firmware.hex          Optional Arduino firmware (flashed via avrdude)
```

## QEMU Testing

```bash
make qemu      # Boot from slot A (root=/dev/vda2)
make qemu-b    # Boot from slot B (root=/dev/vda3)
```

The update script is QEMU-aware: it detects `vda*` root devices and skips `cmdline.txt` modification (QEMU uses `-append` for the kernel cmdline). The `dd` to the standby partition still works, so the update logic can be exercised.

## What Cannot Be Tested in QEMU

- cmdline.txt swap (QEMU ignores on-disk cmdline.txt)
- USB stick detection (no USB passthrough)
- Actual reboot into other slot
- Display rendering

These require real Pi hardware.

## Open Questions

- **Visual feedback**: The dash should ideally show "Updating..." on screen during the `dd`. Could be a simple framebuffer splash image written before the update starts.
- **Boot partition updates**: If the kernel or DTB needs updating, the update script would also need to write to the boot partition. For now, assume the boot partition is stable and only the rootfs changes.
- **Rollback**: Currently no automatic rollback — if the new image is broken, the old slot is still intact but requires manual intervention (swap cmdline.txt back, or reflash). U-Boot with bootcount could be added later if needed.

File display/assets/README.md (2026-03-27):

# TFT Dash Assets

This directory contains all graphical assets for the TFT Dash display application.

## Structure

```
assets/
└── themes/
    ├── default/       (91 files) - White/default theme
    ├── blue/          (81 files) - Blue theme
    ├── bright/        (84 files) - High-contrast bright theme
    ├── dark/          (81 files) - Dark theme
    ├── green/         (81 files) - Green theme
    ├── night/         (81 files) - Night theme
    ├── orange/        (81 files) - Orange theme
    ├── red/           (81 files) - Red theme
    ├── yellow/        (81 files) - Yellow theme
```

Each theme directory also contains its own `{theme_name}thumb.bmp` preview thumbnail.

**Total: 751 BMP files**

## Theme Files

Each theme directory contains bitmap assets for:

- **Rev gauge segments** (`R0.bmp` through `R12-13.bmp`)
- **Speed numbers** (`Speednumbers.bmp`)
- **Small numbers** for temperature, trip, odometer (`Smallnumbers.bmp`)
- **Indicators** (`Indicateleft.bmp`, `Indicateright.bmp`, `Highbeamlight.bmp`, `Neutrallight.bmp`, `Oillight.bmp`)
- **Warning badges** (`Lowtyrebadge.bmp`, `Lowoilbadge.bmp`, `Overheatbadge.bmp`, `Fuelwarningbadge.bmp`)
- **Gauges** (`Fuelgauge.bmp`, `Coolant.bmp`)
- **Info panels** (`Infotop.bmp`, `Infobottom.bmp`, `Mileinfo.bmp`)
- **Menu graphics** (`Menuoptions.bmp`, `Speedcorrection.bmp`, `Settime.bmp`, `Setunits.bmp`)
- **Navigation graphics** (`Navbg.bmp`, `Navgfx.bmp`)
- **TPMS graphics** (`tyreicon.bmp`, `tyresignal.bmp`, `tyretop.bmp`, `tyrebottom.bmp`)

## Adding a New Theme

1. Create a new directory: `themes/{theme_name}/`
2. Copy BMP files from an existing theme
3. Modify colours/contrast as needed
4. Create a thumbnail: `{theme_name}thumb.bmp` inside the theme directory
5. Update `main.c` to add theme selection logic

## File Format

- **Format**: Windows BMP (bitmap)
- **Colour depth**: Varies by file (typically 24-bit RGB)
- **Dimensions**: Specific to each graphic element
- **Screen resolution**: 1024x600 target display

## Theme Selection

Theme is controlled by:
1. **Firmware setting** - Stored in EEPROM, sent via serial protocol (field 20)
2. **Menu system** - On-screen theme selector in display app
3. **Auto day/night** - Can switch based on ambient light sensor

## Loading Mechanism

Assets are loaded at startup via `asset_store_load_theme()` into a hash map. Textures are retrieved by name:

```c
tex("Coolant.bmp")                          // current theme
tex_from("blue", "bluethumb.bmp")           // specific theme
```

## Deployment

When deploying to Raspberry Pi, ensure:
- `dashboard` binary and `assets/` directory are in the same location
- Relative path `assets/themes/` must be accessible from working directory
- All BMP files have correct permissions (readable)

## Asset Creation Guidelines

When creating or modifying BMP assets:

1. **Maintain dimensions** - Display code expects specific sizes
2. **Use consistent colour palette** per theme
3. **Test on target hardware** - Colours may appear different on TFT display
4. **Optimize file size** - Use RLE compression if supported
5. **Name consistently** - Follow existing naming conventions

## Memory Considerations

- BMPs are loaded into SDL surfaces at startup
- Each surface is converted to an SDL texture
- Total texture memory: ~50-100MB depending on theme
- Theme changes require reloading all surfaces

## Troubleshooting

**Black screen on startup:**
- Check `assets/themes/` path is correct relative to binary
- Verify BMP files exist and are readable
- Check stderr output for SDL_LoadBMP errors

**Wrong colours/missing graphics:**
- Ensure correct theme directory name
- Verify all required BMPs exist in theme directory
- Check file permissions

**Out of memory:**
- Reduce number of loaded themes
- Use lower colour depth BMPs
- Close other applications

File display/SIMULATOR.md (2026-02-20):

# Running TFT Dash with the Simulator

The display can now connect to the C# simulator for development and testing without hardware.

## Prerequisites

- .NET 8+ installed
- Simulator located at `../tft-dash-simulator/`

## Quick Start

### Terminal 1: Start the Simulator

```bash
cd ../tft-dash-simulator
dotnet run
```

The simulator will:
- Create a FIFO pipe at `/tmp/tft-dash-pipe`
- Wait for the display to connect
- Show a Terminal.Gui interface for controlling dashboard state
- Output messages at 10 Hz (100ms intervals)

### Terminal 2: Start the Display

```bash
cd display
zig build run
```

The display will:
- Detect the simulator pipe automatically
- Connect and start rendering
- Print "Simulator connected!" to stderr

## Connection Priority

The display checks for connections in this order:

1. **Simulator pipe** `/tmp/tft-dash-pipe` (highest priority)
2. macOS serial ports (`/dev/cu.usbserial-*`, `/dev/cu.usbmodem*`)
3. Linux serial ports (`/dev/ttyACM0`, `/dev/ttyACM1`)

This means the simulator is always used if available, making it safe for development without accidentally connecting to real hardware.

## Troubleshooting

### "Simulator connected!" but no data
- The simulator blocks until a reader connects
- Make sure both are running simultaneously
- Check that `/tmp/tft-dash-pipe` exists

### Display not connecting to simulator
- Ensure simulator started first (it creates the pipe)
- Check simulator console for "TFT Dash display connected."
- Try: `ls -l /tmp/tft-dash-pipe` to verify pipe exists

### Want to use real hardware instead
Stop the simulator - the display will automatically fall back to serial ports.

## Simulator Controls

See the simulator's Terminal.Gui interface for:
- Speed, RPM, temperature sliders
- Indicator toggles (neutral, oil, high beam, turn signals)
- Preset scenarios (idle, cruising, highway, etc.)
- Navigation message input

## Message Format

The simulator generates the exact same protocol as the firmware:

- **Live data**: `{,speed,rpm,coolant,battery,hour,minute,fuel,...,}`
- **Menu data**: `[,menustate,odo1,odo2,...,settings,...,]`

Messages are validated before sending to ensure protocol compliance.

## Development Workflow

1. **Modify parser** - Update `parser.c` and run `test_parser`
2. **Test with simulator** - Start simulator, run display, verify changes
3. **Real hardware test** - Stop simulator, test on actual bike

The simulator makes rapid iteration possible without hardware setup.

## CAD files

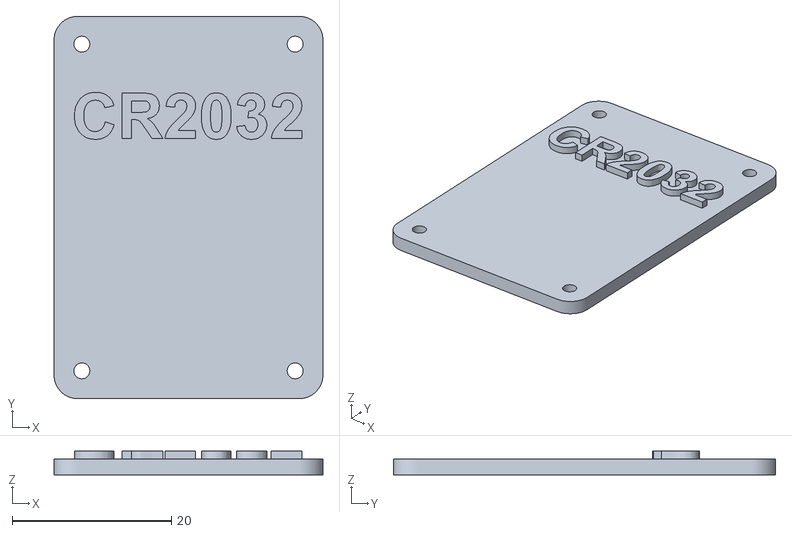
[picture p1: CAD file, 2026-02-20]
hardware/3DModels/BattCover1st.stl
33.8 x 48.1 x 3.00

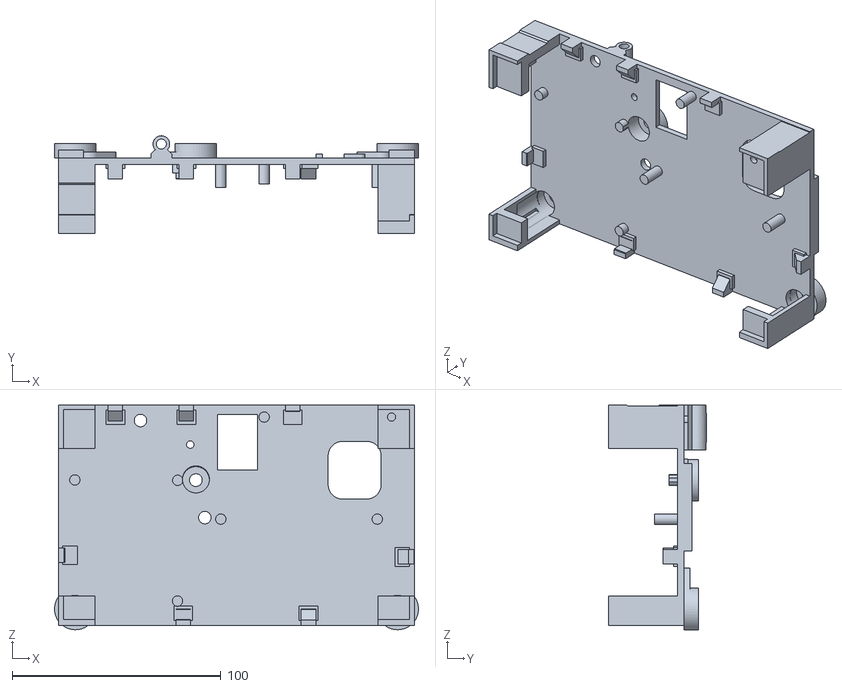
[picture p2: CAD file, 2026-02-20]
hardware/3DModels/CompactBaseV6.stl
174.4 x 46.7 x 107.6

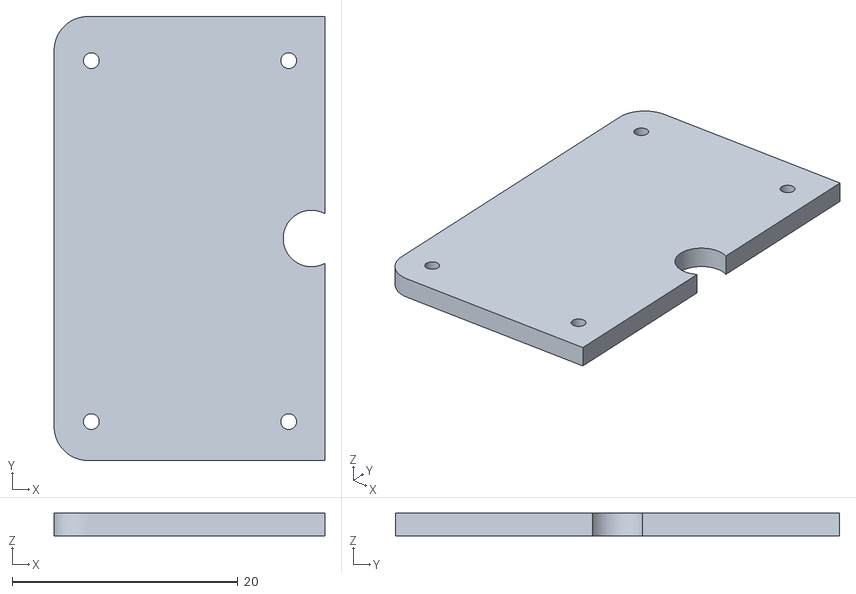
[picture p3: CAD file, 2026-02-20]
hardware/3DModels/ButtonBoxLidV3.stl
24.0 x 39.4 x 2.00

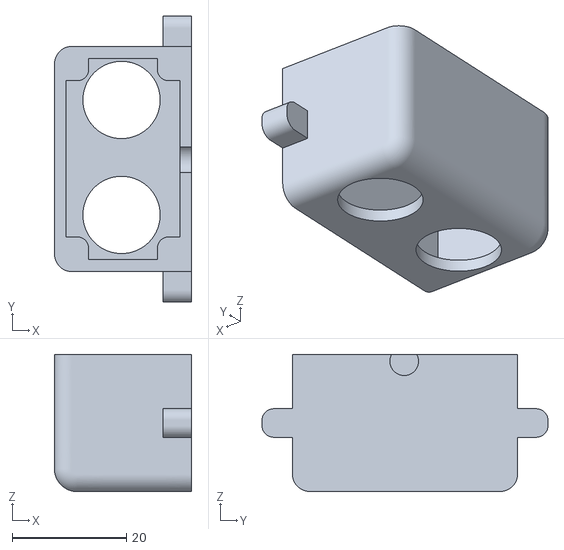
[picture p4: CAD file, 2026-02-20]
hardware/3DModels/ButtonBox.stl
24.0 x 50.0 x 24.0

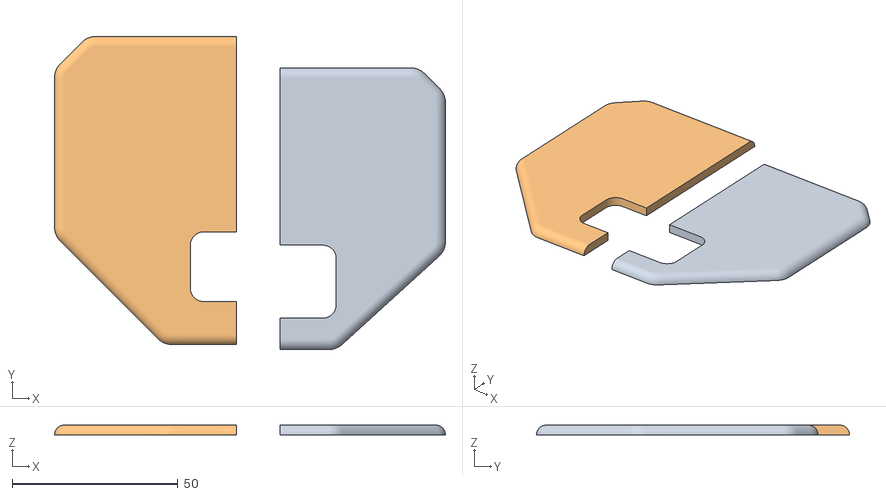
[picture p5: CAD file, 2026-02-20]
hardware/3DModels/TFTDashSideCoversV2.stl
118.0 x 94.5 x 3.00

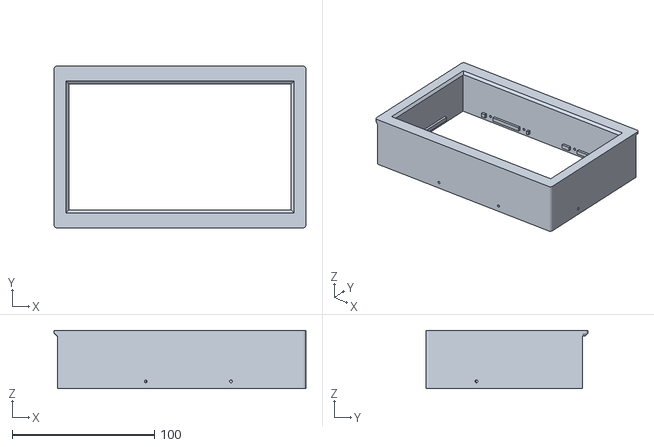
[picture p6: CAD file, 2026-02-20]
hardware/3DModels/CompactCoverV6.stl
177.4 x 113.8 x 40.8

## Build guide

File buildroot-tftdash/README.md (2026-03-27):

# Buildroot Image

Builds a minimal SD card image for the Raspberry Pi 3 that boots directly into the TFT Dash display application.

## What's in the image

- Linux kernel (Pi 3 optimised)
- Busybox (minimal userspace)
- SDL3 (KMS/DRM backend, statically linked)
- avrdude (for firmware flashing via USB updates)
- TFT Dash binary + BMP assets
- Read-only root filesystem
- A/B rootfs update support (two rootfs partitions + update scripts)

No systemd, no desktop, no network services — just the kernel and the dash app.

## SD Card Partition Layout

The image uses an A/B rootfs scheme for atomic updates:

```
p1  boot      32MB   FAT32   kernel, DTBs, firmware, config.txt, cmdline.txt
p2  rootfs_a  512MB  ext4    active Buildroot rootfs (read-only)
p3  rootfs_b  512MB  ext4    standby — dd target for updates
p4  data      16MB   ext4    persistent data (rw) — update log, future use
```

Both rootfs slots contain the same image on initial flash. The active slot is determined by the `root=` parameter in `cmdline.txt` on the boot partition. See `docs/ab-update-plan.md` for full details.

## Prerequisites

1. **Buildroot** cloned as a sibling directory:
   ```bash
   git clone https://github.com/buildroot/buildroot.git ../buildroot-src
   ```

2. **Display binary** pre-built for ARM:
   ```bash
   cd ../display
   zig build -Dtarget=aarch64-linux-gnu -Doptimize=ReleaseSafe
   ```

3. Standard build tools (`gcc`, `make`, `patch`, `unzip`, `rsync`, etc.)

## Building

```bash
# First build (downloads toolchain + kernel, takes 20-30 mins)
./build.sh

# After changing app binary or assets
./build.sh rebuild

# Build a USB update package
./build.sh update-package

# Full clean
./build.sh clean
```

The output is `../buildroot-src/output/images/sdcard.img`.

## Flashing

```bash
sudo dd if=../buildroot-src/output/images/sdcard.img of=/dev/sdX bs=4M status=progress
```

Replace `/dev/sdX` with your SD card device.

## USB Updates

After building a new image, create an update package:

```bash
./build.sh update-package
```

This produces an `update-package/tftupdate/` directory containing:
- `rootfs.img` — full ext4 rootfs image
- `rootfs.img.sha256` — SHA-256 checksum
- `firmware.hex` — Arduino firmware (if available)

Copy the `tftupdate/` directory to a FAT32 USB stick. Plug it into the Pi and reboot — the `S10usbupdate` init script detects the update at boot, writes the image to the standby rootfs partition, flips `cmdline.txt`, and reboots into the new slot.

## Structure

```
buildroot-tftdash/
├── build.sh                  Build wrapper script
├── configs/
│   └── tftdash_defconfig     Buildroot configuration
├── package/tftdash/
│   ├── Config.in             Package menu entry
│   └── tftdash.mk            Package recipe (installs pre-built binary + assets)
├── board/
│   ├── genimage.cfg          SD card partition layout (4-partition A/B scheme)
│   └── post-image.sh         Generates cmdline.txt and final SD card image
├── overlay/                  Files overlaid onto the root filesystem
│   ├── boot/
│   │   └── config.txt        Pi boot config (DPI display, fast boot)
│   ├── data/
│   │   └── .keep             Mountpoint for persistent data partition
│   ├── etc/
│   │   ├── fstab             A/B-aware mounts (no root entry, /data on p4)
│   │   └── init.d/
│   │       ├── S10usbupdate  Boot-time USB update scan
│   │       └── S99tftdash    Init script (starts the dashboard)
│   └── usr/bin/
│       └── tft-update.sh     Core A/B update script
├── external.desc             BR2_EXTERNAL descriptor
├── external.mk               External package includes
└── Config.in                 External package menu
```

## How it works

This uses Buildroot's [BR2_EXTERNAL](https://buildroot.org/downloads/manual/manual.html#outside-br-custom) mechanism. Our custom configs, packages, and overlays live in this directory while Buildroot itself is a separate checkout. The `build.sh` script ties them together.

The Zig cross-compiler builds the `dashboard` binary separately. The Buildroot package recipe (`tftdash.mk`) just copies the pre-built binary and BMP assets into the image — it doesn't compile anything.

## Boot sequence

1. GPU loads `bootcode.bin` → `start.elf` → reads `config.txt`
2. Kernel boots with `quiet fastboot noswap ro` — minimal console output
3. Busybox init runs `/etc/init.d/S10usbupdate start` — scans for USB update stick
4. If update found: writes to standby partition, reboots into new slot
5. If no update: `/etc/init.d/S99tftdash start` — dashboard appears

Target: kernel to app in ~3-5 seconds (add ~1 second when no USB present due to enumeration wait).

## Customising

- **Boot config**: Edit `overlay/boot/config.txt`
- **Add packages**: Edit `configs/tftdash_defconfig`, add `BR2_PACKAGE_FOO=y`
- **Change init**: Edit `overlay/etc/init.d/S99tftdash`
- **Update script**: Edit `overlay/usr/bin/tft-update.sh`
- **Full reconfigure**: `cd ../buildroot-src && make BR2_EXTERNAL=../buildroot-tftdash menuconfig`

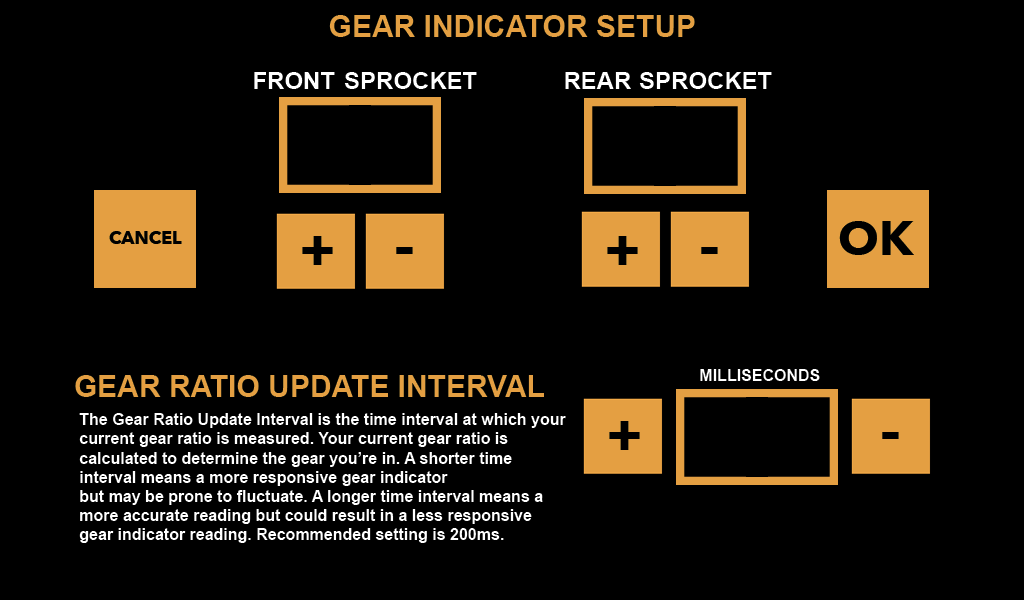
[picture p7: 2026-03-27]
display/assets/themes/night/Sprocketsetup.png

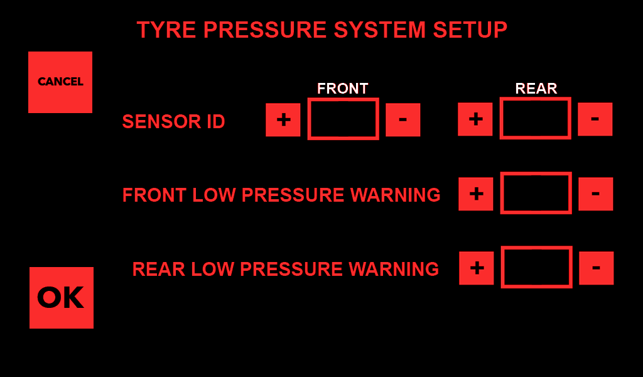
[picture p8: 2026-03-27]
display/assets/themes/red/TPMSsetup.png

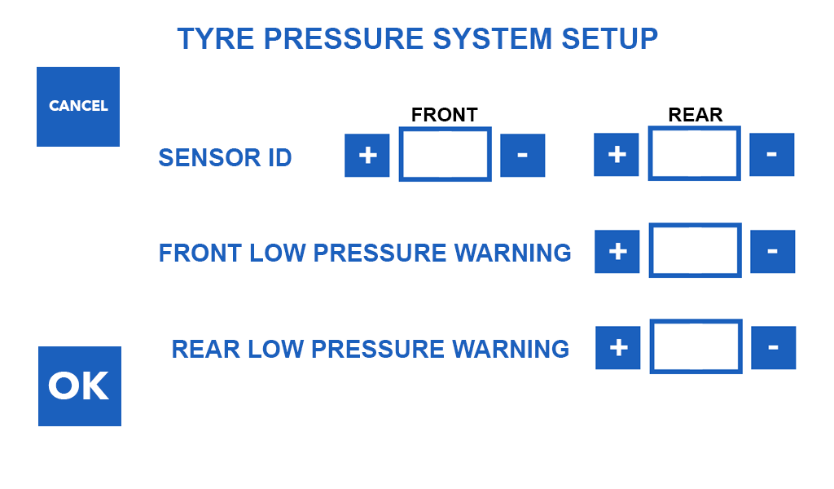
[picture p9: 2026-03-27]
display/assets/themes/default/TPMSsetup.png

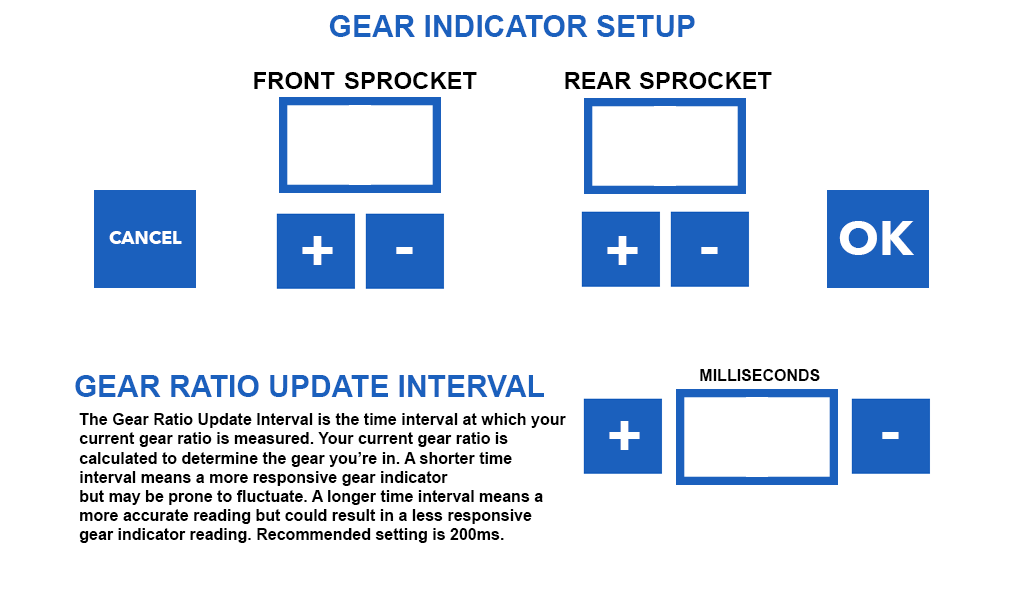
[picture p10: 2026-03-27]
display/assets/themes/bright/Sprocketsetup.png

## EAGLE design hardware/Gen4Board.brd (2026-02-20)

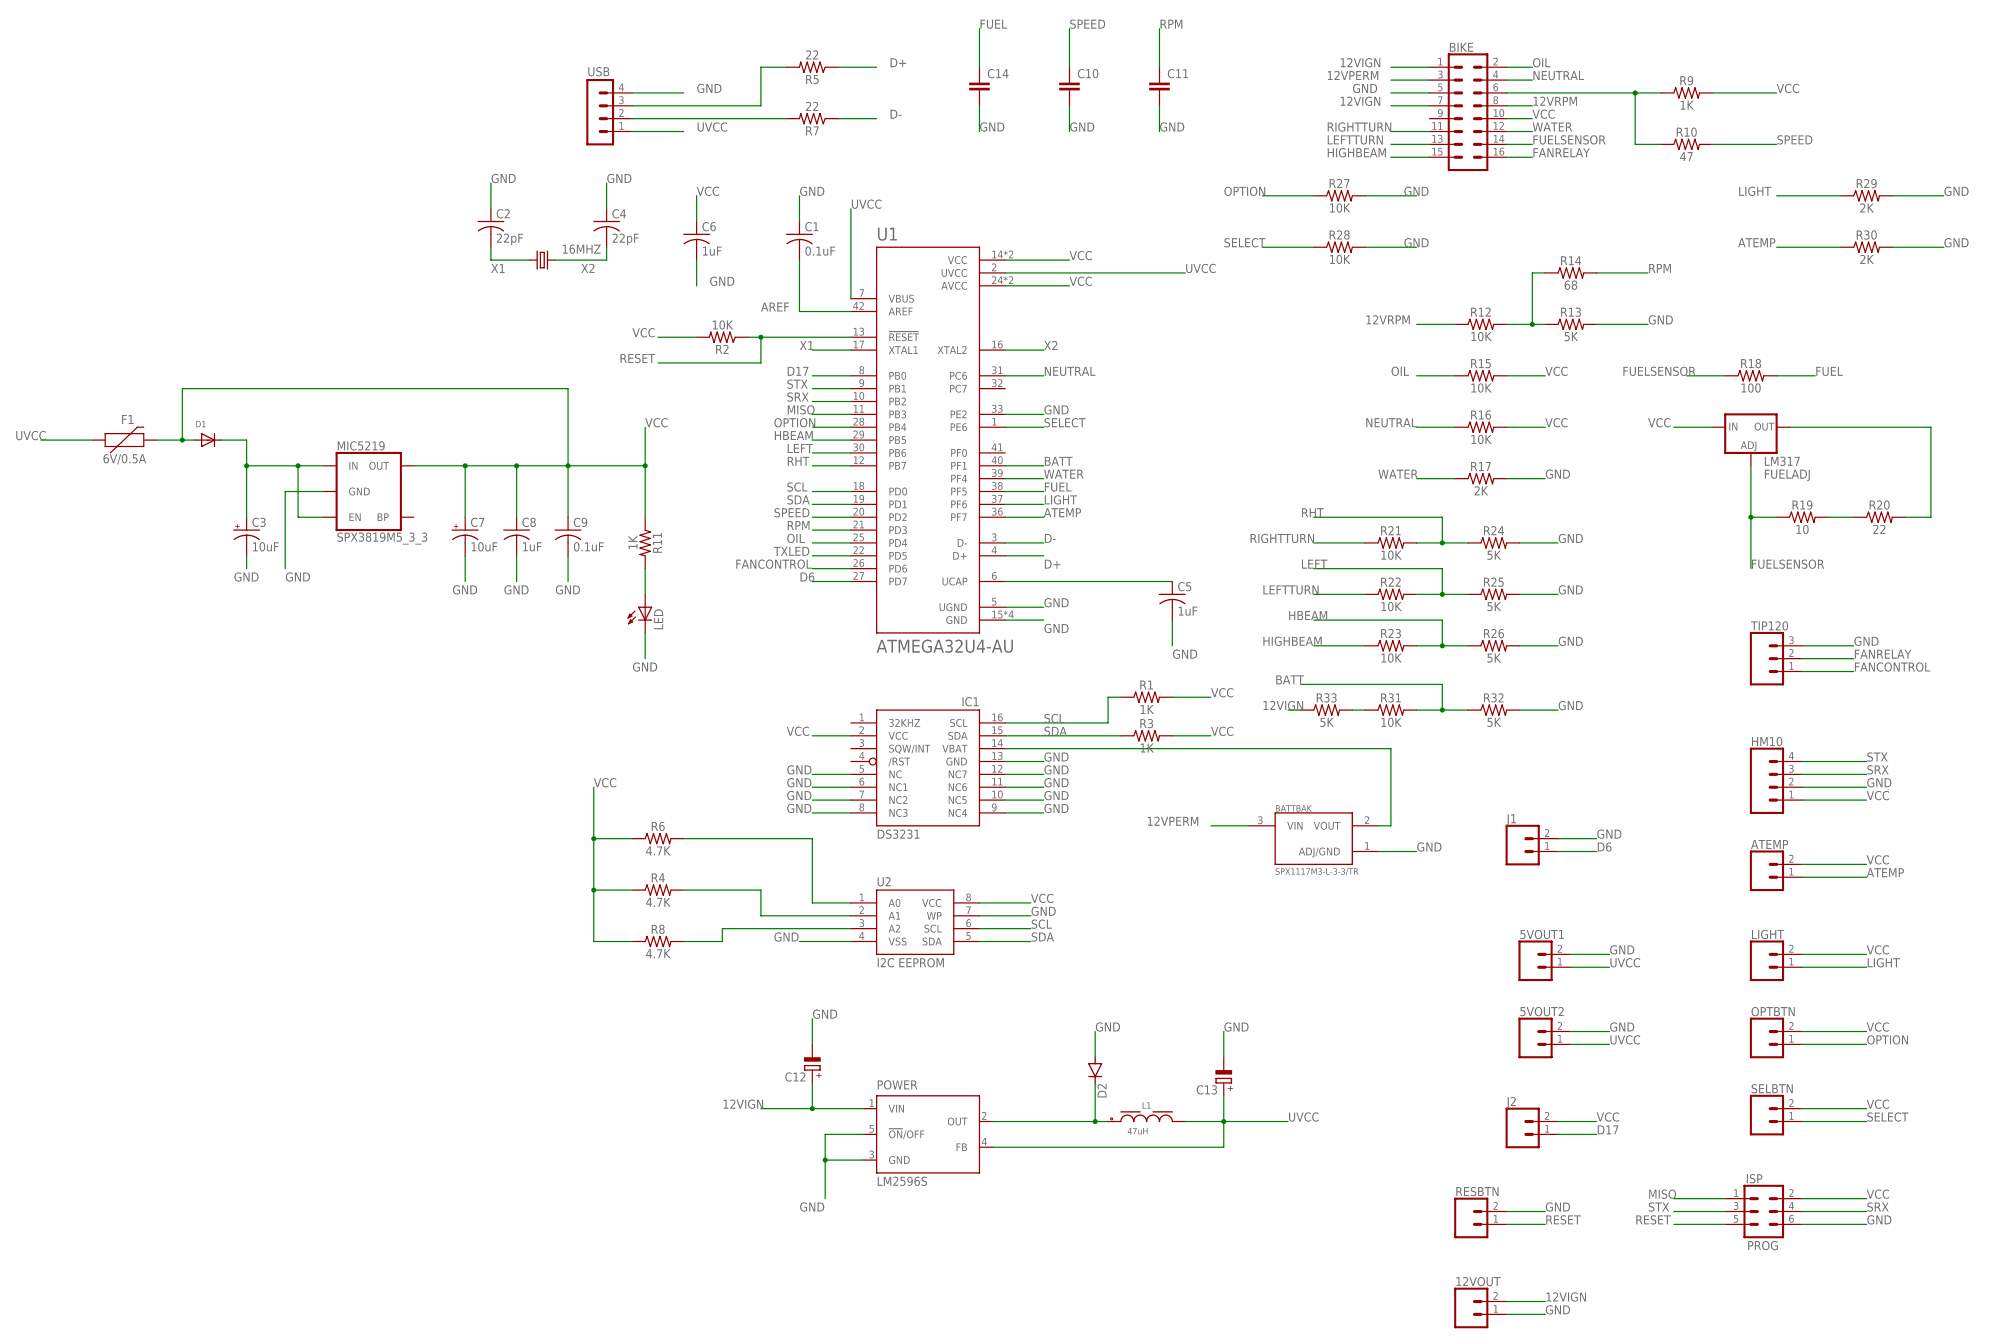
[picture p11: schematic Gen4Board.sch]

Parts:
5VOUT1, 5VOUT2, 12VOUT: CONN_02; 1X02
16MHZ: KX-9A; 5.0X3.2_KX-9A
ATEMP: CONN_02; 1X02
BATTBAK: SPX1117M3-L-3-3/TR; SOT230P700X180-3N
BIKE: CONN_08X2; 2X8
C1, C9: 0.1uF; C0603
C2, C4: 22pF; C0603
C3, C7: 10uF; EIA3216
C5, C6, C8: 1uF; C0603
C10, C11, C14: C2,5-3; C2.5-3
C12, C13: CPOL-EUTT5D10; TT5D10
D1: DIODESOD-323F; SOD-323F
D2: DIODE-DO214AC; DO214AC
F1: 6V/0.5A; 1206
HM10: CONN_04; 1X04
IC1: DS3231/SO; SO16W
ISP: PROG; 2X3
J1, J2: CONN_02; 1X02
L1: 47uH; WE-PD_1260
LED: LEDCHIPLED_0603; CHIPLED_0603
LIGHT: CONN_02; 1X02
LM317: FUELADJ; TO220-ADJ
MIC5219: SPX3819M5_3_3; SOT23-5
OPTBTN: CONN_02; 1X02
POWER: LM2596S; TO263-5
R1, R3, R11: 1K; 0603
R2: 10K; 0603
R4, R6, R8: 4.7K; 0603
R5, R7: 22; 0603
R9: 1K; 1206
R10: 47; 1206
R12, R15, R16, R21, R22, R23, R27, R28, R31: 10K; 1206
R13, R24, R25, R26, R32, R33: 5K; 1206
R14: 68; 1206
R17, R29, R30: 2K; 1206
R18: 100; 1206
R19: 10; 1206
R20: 22; 1206
RESBTN: CONN_02; 1X02
SELBTN: CONN_02; 1X02
TIP120: CONN_03; 1X03
U1: ATMEGA32U4-AU; QFP80P1200X1200X120-44N
U2: I2C EEPROM; SO08-EIAJ
USB: MA04-1

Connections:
12VIGN: 12VOUT.2, BIKE.1, BIKE.7, C12.+, POWER.1 (VIN), R33.1
12VPERM: BATTBAK.3 (VIN), BIKE.3
12VRPM: BIKE.8, R12.1
AREF: C1.2, U1.42 (AREF)
ATEMP: ATEMP.1, R30.1, U1.36 (PF7)
BATT: R31.2, R32.1, U1.40 (PF1)
D6: J1.1, U1.27 (PD7)
D17: J2.1, U1.8 (PB0)
D+: R5.1, U1.4 (D+)
D-: R7.1, U1.3 (D-)
FANCONTROL: TIP120.1, U1.26 (PD6)
FANRELAY: BIKE.16, TIP120.2
FUEL: C14.1, R18.2, U1.38 (PF5)
FUELSENSOR: BIKE.14, LM317.ADJ, R18.1, R19.1
GND: 5VOUT1.2, 5VOUT2.2, 12VOUT.1, BATTBAK.1 (ADJ/GND), BIKE.5, C1.1, C2.1, C3.-, C4.1, C5.2, C6.2, C7.-, C8.2, C9.2, C10.2, C11.2, C12.-, C13.-, C14.2, D2.A, HM10.2, IC1.5 (NC), IC1.6 (NC1), IC1.7 (NC2), IC1.8 (NC3), IC1.9 (NC4), IC1.10 (NC5), IC1.11 (NC6), IC1.12 (NC7), IC1.13 (GND), ISP.6, J1.2, LED.C, MIC5219.2 (GND), POWER.3 (GND), POWER.5 (!ON!/OFF), R13.2, R17.2, R24.2, R25.2, R26.2, R27.2, R28.2, R29.2, R30.2, R32.2, RESBTN.2, TIP120.3, U1.5 (UGND), U1.15 (GND), U1.23 (GND), U1.33 (PE2), U1.35 (GND), U1.43 (GND), U2.4 (VSS), U2.7 (WP), USB.4
HBEAM: R23.2, R26.1, U1.29 (PB5)
HIGHBEAM: BIKE.15, R23.1
LEFT: R22.2, R25.1, U1.30 (PB6)
LEFTTURN: BIKE.13, R22.1
LIGHT: LIGHT.1, R29.1, U1.37 (PF6)
MISO: ISP.1, U1.11 (PB3)
unnamed: R7.2, USB.2
unnamed: R5.2, USB.3
unnamed: C5.1, U1.6 (UCAP)
unnamed: LED.A, R11.2
unnamed: C3.+, D1.C, MIC5219.1 (IN), MIC5219.3 (EN)
unnamed: R6.2, U2.1 (A0)
unnamed: R4.2, U2.2 (A1)
unnamed: BATTBAK.2 (VOUT), IC1.14 (VBAT)
unnamed: R8.2, U2.3 (A2)
unnamed: BIKE.6, R9.1, R10.1
unnamed: LM317.OUT, R20.2
unnamed: R12.2, R13.1, R14.1
unnamed: D2.C, L1.1, POWER.2 (OUT)
unnamed: R19.2, R20.1
unnamed: R31.1, R33.2
NEUTRAL: BIKE.4, R16.1, U1.31 (PC6)
OIL: BIKE.2, R15.1, U1.25 (PD4)
OPTION: OPTBTN.1, R27.1, U1.28 (PB4)
RESET: ISP.5, R2.1, RESBTN.1, U1.13 (!RESET)
RHT: R21.2, R24.1, U1.12 (PB7)
RIGHTTURN: BIKE.11, R21.1
RPM: C11.1, R14.2, U1.21 (PD3)
SCL: IC1.16 (SCL), R1.1, U1.18 (PD0), U2.6 (SCL)
SDA: IC1.15 (SDA), R3.1, U1.19 (PD1), U2.5 (SDA)
SELECT: R28.1, SELBTN.1, U1.1 (PE6)
SPEED: C10.1, R10.2, U1.20 (PD2)
SRX: HM10.3, ISP.4, U1.10 (PB2)
STX: HM10.4, ISP.3, U1.9 (PB1)
TXLED: U1.22 (PD5)
UVCC: 5VOUT1.1, 5VOUT2.1, C13.+, F1.1, L1.2, POWER.4 (FB), U1.2 (UVCC), U1.7 (VBUS), USB.1
VCC: ATEMP.2, BIKE.10, C6.1, C7.+, C8.1, C9.1, D1.A, F1.2, HM10.1, IC1.2 (VCC), ISP.2, J2.2, LIGHT.2, LM317.IN, MIC5219.5 (OUT), OPTBTN.2, R1.2, R2.2, R3.2, R4.1, R6.1, R8.1, R9.2, R11.1, R15.2, R16.2, SELBTN.2, U1.14 (VCC), U1.24 (AVCC), U1.34 (VCC), U1.44 (AVCC), U2.8 (VCC)
WATER: BIKE.12, R17.1, U1.39 (PF4)
X1: 16MHZ.1, C2.2, U1.17 (XTAL1)
X2: 16MHZ.3 (2), C4.2, U1.16 (XTAL2)

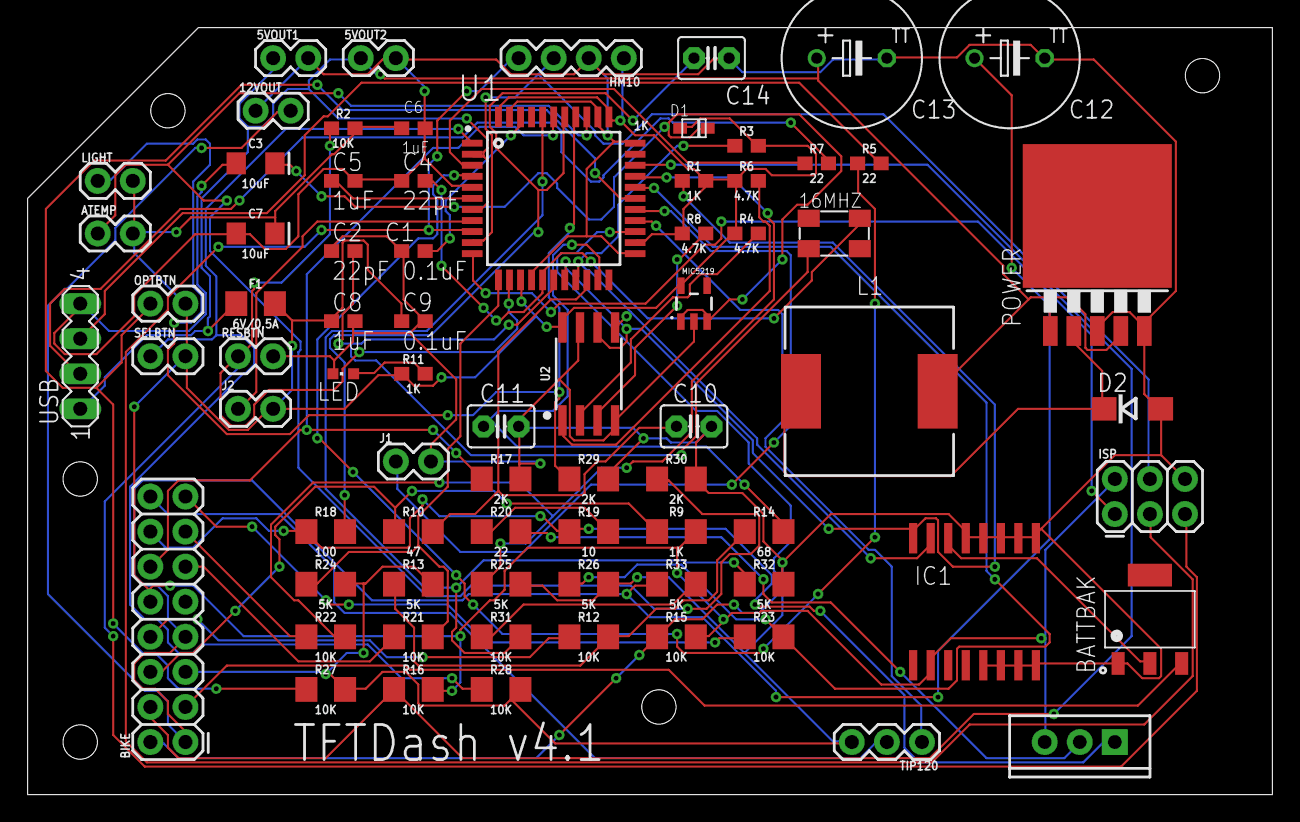
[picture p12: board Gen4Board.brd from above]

Board: 2 copper layers, 90.2 x 55.5 mm, 75 parts (0 on the bottom side), 54 nets.

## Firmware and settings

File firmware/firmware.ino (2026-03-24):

// Bike model selection - uncomment ONE
//#define BIKE_FZS1000
#define BIKE_FZS600

#include <Eeprom24C32_64.h>

#include <Wire.h>
#include <util/atomic.h>
#include "RTClib.h"

#include <SoftwareSerial.h>

// Pin Mapping (Gen4 board — ATMega32u4)
#define SPEEDSENSORPIN 0
#define RPMSENSORPIN  1
#define FUELPIN     A2
#define COOLANTPIN  A3
#define BATTERYPIN  A4
#define OILLEVELPIN   4 // Goes LOW when oil level is ok 
#define NEUTRALPIN  5 // Goes LOW when in Neutral
#define HIGHBEAMPIN 9 // Goes high when Lit
#define FANPIN   12  // Set high to turn on fan
#define INDICATELEFTPIN  10 // Goes HIGH when lit
#define INDICATERIGHTPIN  11 // Goes HIGH when lit
#define AMBIENTTEMPPIN  A0
#define LIGHTSENSORPIN  A1
// Option and Select buttons
#define OPTIONPIN 8
#define SELECTPIN 7

#define EEPROM_ADDRESS 0x57

// Bike-specific constants
#ifdef BIKE_FZS1000
  #define RPM_CONSTANT          29.60
  #define WHEEL_DIAMETER_M      0.629   // 180/55 ZR17
  #define PRIMARY_DRIVE_RATIO   1.581   // 68/43
  #define GEAR1_RATIO           ((double)35 / 14)  // 2.500
  #define GEAR2_RATIO           ((double)35 / 19)  // 1.842
  #define GEAR3_RATIO           ((double)30 / 20)  // 1.500
  #define GEAR4_RATIO           ((double)28 / 21)  // 1.333
  #define GEAR5_RATIO           ((double)30 / 25)  // 1.200
  #define GEAR6_RATIO           ((double)29 / 26)  // 1.115
#endif

#ifdef BIKE_FZS600
  #define RPM_CONSTANT          29.60
  #define WHEEL_DIAMETER_M      0.624   // 160/60 ZR17
  #define PRIMARY_DRIVE_RATIO   1.708   // 82/48
  #define GEAR1_RATIO           ((double)37 / 13)  // 2.846
  #define GEAR2_RATIO           ((double)37 / 19)  // 1.947
  #define GEAR3_RATIO           ((double)34 / 22)  // 1.545
  #define GEAR4_RATIO           ((double)28 / 21)  // 1.333
  #define GEAR5_RATIO           ((double)25 / 21)  // 1.190
  #define GEAR6_RATIO           ((double)29 / 27)  // 1.074
#endif

// MENU OPTION DEFINITIONS - mapped to choicestate and menulevel
#define MAINDASHBOARD        0
#define RESETTRIP1          1
#define RESETTRIP2          2

#define CONTROLSETUP        3
#define CONTROLCANCEL       300
#define CONTROLLAYOUT1        301
#define CONTROLLAYOUT2        302
#define CONTROLOK         303

#define SETUNITS          4
#define SETUNITSCANCEL        400
#define SETUNITSMILES         401
#define SETUNITSKM          402
#define SETUNITSCELCIUS       403
#define SETUNITSFARENHEIT       404
#define SETUNITSPSI         405
#define SETUNITSBAR         406
#define SETUNITSOK          407

#define SETTIME           5
#define SETTIMECANCEL         500
#define SETTIMEDIGIT1         501
#define SETTIMEDIGIT2         502
#define SETTIMEDIGIT3         503
#define SETTIMEDIGIT4         504
#define SETTIMEOK           505

#define AMBIENTLIGHTSETUP       6
#define AMBIENTLIGHTCANCEL      600
#define DAYTHEMEPLUS        601
#define DAYTHEMEMINUS         602
#define NIGHTTHEMEPLUS        603
#define NIGHTTHEMEMINUS       604
#define LIGHTLEVELPLUS        605
#define LIGHTLEVELMINUS       606
#define AMBIENTLIGHTOK        607

#define SPEEDCORRECTIONMENU     7
#define SPEEDCORRECTIONCANCEL     700
#define SPEEDCORRECTIONPLUSMINUS  701
#define SPEEDCORRECTIONDIGIT1     702
#define SPEEDCORRECTIONDIGIT2     703
#define SPEEDCORRECTIONDIGIT3     704
#define SPEEDCORRECTIONOK       705

#define SETDISPLAYTHEME       8
#define DEFAULTTHEMEWHITE       800
#define GREENTHEME          801
#define REDTHEME          802
#define BLUETHEME           803
#define ORANGETHEME         804
#define YELLOWTHEME         805
#define HCWHITETHEME        806
#define NIGHTTHEME          807
#define HCDARKTHEME         808

#define GEARINDICATORSETUP      9
#define GEARINDICATORCANCEL     900
#define FRONTSPROCKETPLUS       901
#define FRONTSPROCKETMINUS      902
#define REARSPROCKETPLUS      903
#define REARSPROCKETMINUS       904
#define UPDATEINTERVALPLUS      905
#define UPDATEINTERVALMINUS     906
#define GEARINDICATOROK       907

#define COOLANTFANSETUP       10
#define COOLANTSETUPCANCEL      1000
#define COOLANTFANPLUS        1001
#define COOLANTFANMINUS       1002
#define FANMODEALWAYS         1003
#define FANMODE1MINUTE        1004
#define FANMODE50DEGREES      1005
#define FANMODETHROTTLEBLIP     1006
#define COOLANTSETUPOK        1007

#define TPMSSETUP           11
#define TPMSCANCEL          1100
#define FRONTSENSORPLUS       1101
#define FRONTSENSORMINUS      1102
#define REARSENSORPLUS        1103
#define REARSENSORMINUS       1104
#define FRONTLOWPLUS        1105
#define FRONTLOWMINUS         1106
#define REARLOWPLUS         1107
#define REARLOWMINUS        1108
#define TPMSOK            1109

#define ODOSETUP          12
#define ODODIGIT1         1200
#define ODODIGIT2         1201
#define ODODIGIT3         1202
#define ODODIGIT4         1203
#define ODODIGIT5         1204
#define ODODIGIT6         1205
#define ODOCONDIGIT1        1206
#define ODOCONDIGIT2        1207
#define ODOCONDIGIT3        1208
#define ODOCONDIGIT4        1209
#define ODOCONDIGIT5        1210
#define ODOCONDIGIT6        1211
#define ODOOK            1212

// Global Variables
char szNav[255];

volatile unsigned long last_speed_interrupt_time;
volatile bool speedpulsehigh = false;
volatile unsigned int speedpulse_time;

volatile unsigned long avgrpmsum = 0;
volatile unsigned long avgrpmpulse_time = 0;
volatile unsigned long avgrpmpointer = 0;

volatile unsigned long last_rpm_interrupt_time;
volatile bool rpmpulsehigh = false;
volatile unsigned long rpmtimer_start;
volatile unsigned long rpmpulse_time;

unsigned int nv_speedpulse_time;
unsigned int nv_avgspeedpulse_time;
unsigned long nv_rpmpulse_time;
unsigned long nv_last_rpm_interrupt_time;
unsigned long nv_last_speed_interrupt_time;

// Floating speed and speed averaging
unsigned long floatingspeedtime = 0;
unsigned int floatingspeed = 0;
int speedAvgpointer = 0;
int speedsum = 0;
int calcspeedAvg = 0;

// RPM and Floating RPM
int rpm = 0;
unsigned long rpmspeedtime = 0;
unsigned int floatingrpm = 0;
unsigned long rpmAvgpointer = 0;
unsigned long rpmsum = 0;
unsigned long calcrpmAvg = 0;
bool enginerunningten = false;


// Analog sensors
unsigned long senschecktime = 0;
int coolanttemp = 0;
int ambienttemp = 0;
double battvoltage = 0;

// Gear Indicator
int currentgear = 0;
unsigned long gearratiotime = 0;
int floatinggearratio = 0;

// Max Speed
int maxspeed;

// Trip time
int triptimemin = 0;
int triptimehour = 0;
int triptimesec = 0;
unsigned long triptimemillis;

// Dash lights
int neutrallight = 0;
unsigned long timeinneutral = 0;
bool neutraldelaydone = false;

int highbeamlight = 0;
int oillight = 0;
int leftlight = 0;
int rightlight = 0;

// MPG and Range
double litresremaining = 0;
double milesperlitre = 0;
double litresused = 0;
double safempg = 0;
unsigned long avgmpgcount = 0;
unsigned long avgmpg = 0;
double saferange = 0;

// Trip calculation
unsigned long speedchecktime = 0;
double currentspeedperms = 0;
double elapsedspeedtime = 0;
double odotrip = 0; // new values to add to the odometer as it appears with large odo values, the odometer won't increase. (Maybe too many CPU cycles with interrupts going on?)
double lasttrip1 = 0;
double lasttrip2 = 0;
double lastodo = 0;
double lastodotrip = 0;
double startupodo = 0;
double realodo = 0;

// Saved Settings values
int sig = 0;  
int sig2 = 0;
int sig3 = 0;
int sig4 = 0;
int sig5 = 0;
int gearratiointerval = 200;
int frontsprocket = 16;
int rearsprocket = 44;
double trip1 = 0;
double trip2 = 0;
double speedcorrection = 0;
bool km = false;
int theme = 0;
int coolantfantemp = 100;
double lastlitresremaining = 0;
double lastfuelodo = 0; // EXPERIMENT!
int mpg = 0;
int range = 0;
double litresatfillup = 0;
double odo = 0; // EXPERIMENT!
bool fh = false;
bool bar = false;
int frontsensor = 2;
int rearsensor = 4;
int frontpressurelow = 20;
int rearpressurelow = 20;
int controllayout = 0;
int daytheme = 0;
int nighttheme = 6;
int lightswitchvalue = 0;
int fanneutraloption = 0;

bool hardreset = false;

// Fuel Level
int fuelresistance = 0;
int fuelAvgpointer = 0;
int fuelsum = 0;
int calcfuelAvg = 0;
int fuelintfloat = -99;
int fuelintfloatlower = -99;
int fuelintfloatupper = -99;
int fuelintfloatmid = -99;

// Coolant Temp and Ambient Temp
int coolantAvgpointer = 0;
int calccoolantAvg = 0;
int coolantsum = 0;

int ambientAvgpointer = 0;
int calcambientAvg = 0;
int ambientsum = 0;

// Additional variables
bool fanactive = false;
bool enginetimestart = false;
unsigned long engineruntime = 0;
int battAvgpointer = 0;
double battsum = 0;
double calcbattAvg = 0;
int infomode = 0;
int choicestate = 0;
unsigned long lastoutputtime = 0;

// Light sensor
unsigned long lightsenstime = 3000;
int currentlightlevel = 0;
unsigned long nightswitchtime = 2000;

//Navigation
int incomingBLEbyte = 0;
char szBLEreadbuf[255];
int bleReadpointer = 0;
bool navactive = false;

// Option and Select buttons  
bool optionButtontriggered = false;
bool selectButtontriggered = false;
bool bothButtontriggered = false;
bool bothButtonfired = false;
unsigned long bothButtontime = 0;
unsigned long buttonTime = 0;
bool menujustentered = false;

//Menu options
int settimedigit0 = 0;
int settimedigit1 = 0;
int settimedigit2 = 0;
int settimedigit3 = 0;

int spcdigit0 = 0;
int spcdigit1 = 0;
int spcdigit2 = 0;
int spcdigit3 = 0;

// Odometer digits
int ododigit1 = 0;
int ododigit2 = 0;
int ododigit3 = 0;
int ododigit4 = 0;
int ododigit5 = 0;
int ododigit6 = 0;

int odo2digit1 = 0;
int odo2digit2 = 0;
int odo2digit3 = 0;
int odo2digit4 = 0;
int odo2digit5 = 0;
int odo2digit6 = 0;

int odoerror = 0;

unsigned long lastfloatchecktime = 0;

//micros when the pin goes HIGH
volatile unsigned long timer_start;
unsigned long timeingear = 0;
int currentspeed = 0;
double speedcorrectamount = 0;

// Global Instances
static Eeprom24C32_64 eeprom(EEPROM_ADDRESS);
SoftwareSerial mySerial(16, 15); // RX, TX

RTC_DS3231 rtc;

//Refactored menu code
int menulimit = 11; // Length of main menu
int currentsubmenu = 0;
int menulevel = 0; // This will be 300, 400 etc... which will be appended to the choicestate

int mlimits[13] = {
  11,
  0,
  0,
  3,
  7,
  5,
  7,
  5,
  8,
  7,
  7,
  9,
  12
};

bool LoadData ()
{
  byte data[90];
  memset (data, 0, 90);
  
  eeprom.readBytes(0, 74, data);
  
  int datapointer = 0;
  unsigned long oldodo = 0;

  memcpy (&sig, data+datapointer, sizeof (int));
  datapointer+=sizeof (int);

  memcpy (&oldodo, data+datapointer, sizeof (unsigned long));
  datapointer+=sizeof (unsigned long);

  memcpy (&trip1, data+datapointer, sizeof (double));
  datapointer+=sizeof (double);

  memcpy (&trip2, data+datapointer, sizeof (double));
  datapointer+=sizeof (double);

  memcpy (&speedcorrection, data+datapointer, sizeof (double));
  datapointer+=sizeof (double);

  memcpy (&km, data+datapointer, sizeof (bool));
  datapointer+=sizeof (bool);

  memcpy (&theme, data+datapointer, sizeof (int));
  datapointer+=sizeof (int);

  byte fs = 0;
  memcpy (&fs, data+datapointer, sizeof (byte));
  datapointer+=sizeof (byte);
  if (fs < 63 && fs > 10) {
    frontsprocket = fs;
  }
  
  byte rs = 0;
  memcpy (&rs, data+datapointer, sizeof (byte));
  datapointer+=sizeof (byte);
  if (rs < 63 && rs > 10) {
    rearsprocket = rs;  
  }
  
  byte cf = 0;
  memcpy (&cf, data+datapointer, sizeof (byte));
  datapointer+=sizeof (byte);
  coolantfantemp = cf;  

  memcpy (&sig2, data+datapointer, sizeof (int));
  datapointer+=sizeof (int);

  if (sig2 == sig) {
    memcpy (&lastlitresremaining, data+datapointer, sizeof (double));
    datapointer+=sizeof (double);

    memcpy (&lastfuelodo, data+datapointer, sizeof (unsigned long));
    datapointer+=sizeof (unsigned long);

    memcpy (&mpg, data+datapointer, sizeof (int));
    datapointer+=sizeof (int);

    memcpy (&range, data+datapointer, sizeof (int));
    datapointer+=sizeof (int);

    // Signature for litres at fillup
    memcpy (&sig3, data+datapointer, sizeof (int));
    datapointer+=sizeof (int);

    if (sig3 == sig) {
      memcpy (&litresatfillup, data+datapointer, sizeof (double));
      datapointer+=sizeof (double);

      // Signature for new odometer reading (as a double)
      memcpy (&sig4, data+datapointer, sizeof (int));
      datapointer+=sizeof (int);

      if (sig4 == sig) {
     
        memcpy (&odo, data+datapointer, sizeof (double));
        datapointer+=sizeof (double);
    
        // Signature for new data for July 2020 update
        memcpy (&sig5, data+datapointer, sizeof (int));
        datapointer+=sizeof (int);

        if (sig5 == sig) {
                   
          memcpy (&fh, data+datapointer, sizeof (bool));
          datapointer+=sizeof (bool); 
          
          memcpy (&bar, data+datapointer, sizeof (bool));
          datapointer+=sizeof (bool);    

          memcpy (&frontsensor, data+datapointer, sizeof (int));
          datapointer+=sizeof (int);

          memcpy (&rearsensor, data+datapointer, sizeof (int));
          datapointer+=sizeof (int);

          memcpy (&frontpressurelow, data+datapointer, sizeof (int));
          datapointer+=sizeof (int);

          memcpy (&rearpressurelow, data+datapointer, sizeof (int));
          datapointer+=sizeof (int);    

          memcpy (&controllayout, data+datapointer, sizeof (int));
          datapointer+=sizeof (int);

          memcpy (&daytheme, data+datapointer, sizeof (int));
          datapointer+=sizeof (int);

          memcpy (&nighttheme, data+datapointer, sizeof (int));
          datapointer+=sizeof (int);

          memcpy (&lightswitchvalue, data+datapointer, sizeof (int));
          datapointer+=sizeof (int);

          memcpy (&fanneutraloption, data+datapointer, sizeof (int));
          datapointer+=sizeof (int);

          memcpy (&gearratiointerval, data+datapointer, sizeof (int));
          datapointer+=sizeof (int);
        }
        
      } else {
        odo = (double)oldodo;
      }
    }
  }

  realodo = odo;
  startupodo = odo;
  
  if (sig == 1808) {

    if (frontsensor < 0 || frontsensor > 9) {
      frontsensor = 2;
    }

    if (rearsensor < 0 || rearsensor > 9) {
      rearsensor = 4;
    }

    if (frontpressurelow < 10 || frontpressurelow > 50) {
      frontpressurelow = 20;
    }

    if (rearpressurelow < 10 || rearpressurelow > 50) {
      rearpressurelow = 20;
    }

    if (controllayout < 0 || controllayout > 1) {
      controllayout = 0;
    }

    if (daytheme < 0 || daytheme > 8) {
      daytheme = 0;
    }

    if (nighttheme < 0 || nighttheme > 8) {
      nighttheme = 6;
    }

    if (lightswitchvalue < 0 || lightswitchvalue > 900) {
      lightswitchvalue = 0;
    }

    if (fanneutraloption < 0 || fanneutraloption > 3) {
      fanneutraloption = 0;
    }

    if (gearratiointerval < 10 || gearratiointerval > 400) {
      gearratiointerval = 200;
    }
    
    return true;
  } else {
    odo = 0;
    realodo = 0;
    startupodo = 0;
    trip1 = 0;
    trip2 = 0;
    speedcorrection = 0;
    km = false;
    fh = false;
    bar = false;
    theme = 0;
    coolantfantemp = 100;
    frontsprocket = 16;
    rearsprocket = 44;
    lastlitresremaining = 0;
    lastfuelodo = 0;
    mpg = 0;
    range = 0;
    litresatfillup = 0;
    frontsensor = 2;
    rearsensor = 4;
    frontpressurelow = 20;
    rearpressurelow = 20;
    controllayout = 0;
    daytheme = 0;
    nighttheme = 6;
    currentlightlevel = 0;
    lightswitchvalue = 0;
    fanneutraloption = 0;
    gearratiointerval = 200;
    
    return false;
  }
  
  return true;
  
}

void SaveData () 
{

  /*
  Data to Save to Eeprom:
  SIGNATURE, ODO, Trip1, Trip2, Speed Correction, Miles / KM, Chosen Theme
  2,         4,   2 .  , 2 .  , 4               , 1         , 2
  */


  int signature = 1808;

  if (hardreset == true) {
    signature = 7777;
  }
  
  int memsize = sizeof (int) + 
  sizeof (unsigned long) + 
  sizeof (double) + 
  sizeof (double) + 
  sizeof (double) + 
  sizeof (bool) + 
  sizeof (int) + 
  sizeof (byte) + 
  sizeof (byte) +
  sizeof (byte) +
  sizeof (int) + 
  sizeof (double) + 
  sizeof (unsigned long) + 
  sizeof (int) + 
  sizeof (int) +
  sizeof (int) + 
  sizeof (double) + 
  sizeof (int) + 
  sizeof (double) +
  sizeof (int) +
  sizeof (bool) + 
  sizeof (bool) + 
  sizeof (int) +
  sizeof (int) + 
  sizeof (int) + 
  sizeof (int) + 
  sizeof (int) +
  sizeof (int) + 
  sizeof (int) + 
  sizeof (int) +
  sizeof (int) + 
  sizeof (int);
  

  


  //2,4,4,4,4,1,2,1,1,1,2,4,4,2,2,2,4,2,4,2,1,1,2,2,2,2,2 = 24 
  
  byte data[memsize];
  int datapointer = 0;
  unsigned long oldodo = 0;
  
  memset (data, 0, memsize);
  
  memcpy (data+datapointer, &signature, sizeof (int));
  datapointer+=sizeof (int);
  
  memcpy (data+datapointer, &oldodo, sizeof (unsigned long));
  datapointer+=sizeof (unsigned long);

  memcpy (data+datapointer, &trip1, sizeof (double));
  datapointer+=sizeof (double);

  memcpy (data+datapointer, &trip2, sizeof (double));
  datapointer+=sizeof (double);

  memcpy (data+datapointer, &speedcorrection, sizeof (double));
  datapointer+=sizeof (double);

  memcpy (data+datapointer, &km, sizeof (bool));
  datapointer+=sizeof (bool);

  memcpy (data+datapointer, &theme, sizeof (int));
  datapointer+=sizeof (int);

  byte fs = frontsprocket;
  memcpy (data+datapointer, &fs, sizeof (byte));
  datapointer+=sizeof (byte);

  byte rs = rearsprocket;
  memcpy (data+datapointer, &rs, sizeof (byte));
  datapointer+=sizeof (byte);

  byte cf = coolantfantemp;
  memcpy (data+datapointer, &cf, sizeof (byte));
  datapointer+=sizeof (byte);

  memcpy (data+datapointer, &signature, sizeof (int));
  datapointer+=sizeof (int);

  memcpy (data+datapointer, &lastlitresremaining, sizeof (double));
  datapointer+=sizeof (double);

  memcpy (data+datapointer, &lastfuelodo, sizeof (unsigned long));
  datapointer+=sizeof (unsigned long);

  memcpy (data+datapointer, &mpg, sizeof (int));
  datapointer+=sizeof (int);

  memcpy (data+datapointer, &range, sizeof (int));
  datapointer+=sizeof (int);  

  memcpy (data+datapointer, &signature, sizeof (int));
  datapointer+=sizeof (int);  

  memcpy (data+datapointer, &litresatfillup, sizeof (double));
  datapointer+=sizeof (double);

  memcpy (data+datapointer, &signature, sizeof (int));
  datapointer+=sizeof (int);

  memcpy (data+datapointer, &odo, sizeof (double));
  datapointer+=sizeof (double);

  // Additional data for July 2020 Update
  memcpy (data+datapointer, &signature, sizeof (int));
  datapointer+=sizeof (int);

  memcpy (data+datapointer, &fh, sizeof (bool));
  datapointer+=sizeof (bool);

  memcpy (data+datapointer, &bar, sizeof (bool));
  datapointer+=sizeof (bool);

  memcpy (data+datapointer, &frontsensor, sizeof (int));
  datapointer+=sizeof (int);

  memcpy (data+datapointer, &rearsensor, sizeof (int));
  datapointer+=sizeof (int);

  memcpy (data+datapointer, &frontpressurelow, sizeof (int));
  datapointer+=sizeof (int);

  memcpy (data+datapointer, &rearpressurelow, sizeof (int));
  datapointer+=sizeof (int);
  
  memcpy (data+datapointer, &controllayout, sizeof (int));
  datapointer+=sizeof (int);

  memcpy (data+datapointer, &daytheme, sizeof (int));
  datapointer+=sizeof (int);

  memcpy (data+datapointer, &nighttheme, sizeof (int));
  datapointer+=sizeof (int);

  memcpy (data+datapointer, &lightswitchvalue, sizeof (int));
  datapointer+=sizeof (int);

  memcpy (data+datapointer, &fanneutraloption, sizeof (int));
  datapointer+=sizeof (int);

  memcpy (data+datapointer, &gearratiointerval, sizeof (int));
  datapointer+=sizeof (int);

  eeprom.writeBytes(0, memsize, data);

  //i2c_eeprom_write_page(0x57, 0, (byte *)data, memsize);

  /*
  // SECOND PAGE
  memcpy (datasecond+datapointersecond, &signature, sizeof (int));
  datapointersecond+=sizeof (int); 

  memcpy (datasecond+datapointersecond, &lastlitresremaining, sizeof (double));
  datapointersecond+=sizeof (double);

  memcpy (datasecond+datapointersecond, &lastfuelodo, sizeof (unsigned long));
  datapointersecond+=sizeof (unsigned long);

  memcpy (datasecond+datapointersecond, &mpg, sizeof (int));
  datapointersecond+=sizeof (int);

  memcpy (datasecond+datapointersecond, &range, sizeof (int));
  datapointersecond+=sizeof (int);

  i2c_eeprom_write_page(0x57, 0x1, (byte *)datasecond, memsizesecond);
  */
}

void Checkbuttoninput ()
{

  // REMOVE FOR PRODUCTION!!!! Allows you to Set Odometer reading by holding down both buttons for 7 seconds
  if (digitalRead (OPTIONPIN) == HIGH && digitalRead (SELECTPIN) == HIGH) {
    if (bothButtontriggered == false) {
      bothButtontriggered = true;
      bothButtontime = millis();
    } else {
      if ((millis() - bothButtontime) > 7000) {
        if (bothButtonfired == false) {
          bothButtonfired = true;

          hardreset = true;
          SaveData ();          
          choicestate = 1200;
        }
      }
    }
  }
  
  
  if (digitalRead (OPTIONPIN) == HIGH && optionButtontriggered == false) {
    optionButtontriggered = true;
    //Serial.println ("OPTION BUTTON");
    if (controllayout == 0) {
      choiceex();  
    } else {
 
      selectex();
    }

  }

  if (digitalRead (SELECTPIN) == HIGH && selectButtontriggered == false) {
    selectButtontriggered = true;
    //Serial.println ("SELECT BUTTON");
    if (controllayout == 0) {
      selectex();  
    } else {
      choiceex();
    }
  } 


  if ((millis() - buttonTime) > 150) {
    buttonTime = millis();
    if (digitalRead (OPTIONPIN) == LOW) {
      optionButtontriggered = false;
      bothButtontriggered = false;
      bothButtonfired = false;
    }
  
    if (digitalRead (SELECTPIN) == LOW) {
      selectButtontriggered = false;
    }
  }
  
}
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
void loop() {

  Checkbuttoninput();

  if ((menulevel+choicestate) == 0) {
    livemode();
    Outputlivedata();
  } else {
    livemode();
    Outputmenudata ();
  }
}

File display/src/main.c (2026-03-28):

/*
 * main.c — TFT Dash entry point
 *
 * Creates sensor feeds, initialises the rendering system, then runs
 * the main loop. No SDL dependency — all rendering is owned by draw.h.
 */

#include "sensor_feed.h"
#include "tpms_feed.h"
#include "animation.h"
#include "warnings.h"
#include "draw.h"

static sensor_feed *feed = NULL;
static tpms_feed *tpms_fd = NULL;

static void init_feeds(void) {
    feed = sensor_feed_create(NULL);
    sensor_feed_start(feed);

    tpms_fd = tpms_feed_create(TPMS_MODEL_EBAY, 2, 4, NULL);
    tpms_feed_start(tpms_fd);
}

int main(void) {
    init_feeds();

    if (!draw_init(
        sensor_feed_dashboard(feed),
        sensor_feed_menu(feed),
        sensor_feed_nav(feed),
        tpms_feed_state(tpms_fd)
    )) return 1;

    for (;;) {
        anim_tick_all();
        warnings_update(
            sensor_feed_dashboard(feed),
            tpms_feed_state(tpms_fd),
            sensor_feed_ms_since_update(feed)
        );
        draw_frame();
    }
}

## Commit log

2026-02-12 Add standalone asset manager module with themed texture lookup
    Extracts BMP loading into a reusable assets.h/c module with a two-key
    hash map for (theme, asset_name) lookups. Includes test suite (7 tests)
    and wires into zig build test alongside the parser tests.
2026-02-12 Integrate asset store into testsdl.cpp, replacing 143 texture globals
    Replace 72 SDL_Surface* and 71 SDL_Texture* globals with a single
    asset_store instance. All 9 themes are loaded upfront at startup via
    asset_store_load_theme(), and textures are retrieved through tex() and
    tex_from() inline helpers. Theme switching becomes a string assignment
    instead of reloading all assets from disk.
    Deletes load_surface(), load_surfaces(), init_textures(), and the
    startup/runtime theme if-ladders (~1250 lines removed, ~40 added).
2026-02-20 Fix TPMS byte comparisons for ARM char signedness
    On ARM, char is unsigned (0-255), so comparing with negative values
    like -86 and -95 is always false. Use (unsigned char) casts with hex
    constants (0xAA, 0xA1) which work correctly on both signed and
    unsigned char platforms.
2026-02-20 Add firmware, simulator, hardware, docs, and config to mono-repo
    Merges the formerly separate tft-dash-firmware and tft-dash-simulator
    repos (both single-commit) plus all previously untracked project files:
    3D models, EAGLE schematics, Pi image config, Buildroot config, and
    project documentation.
    [BattCover1st.stl, ButtonBox.stl, ButtonBoxLidV3.stl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]
2026-02-20 Reorganised some stuff
    [BattCover1st.stl, ButtonBox.stl, ButtonBoxLidV3.stl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]
2026-02-20 Rename directories to match new repo structure and fix stale references
    Rename buildroot/ to buildroot-tftdash/ to distinguish the custom
    external tree from the upstream buildroot-src/ checkout. Update all
    references across docs, build scripts, and build.zig to reflect the
    earlier renames (tftdashdisplay/ -> display/, tftdashfirmwareGEN4/ ->
    firmware/, HardwareGen3/+HardwareGen4/ -> hardware/). Remove obsolete
    Gen3 hardware files and move SERIAL-PROTOCOL.md into docs/.
    [Schematic.brd, Schematic.sch, config.txt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]
2026-02-21 Add firmware build script wrapping arduino-cli
    Provides setup (installs board support + libraries), build, and clean
    subcommands. Used by the top-level Makefile.
2026-02-21 Switch Buildroot Pi image from 32-bit armhf to 64-bit aarch64
    - defconfig: BR2_aarch64, aarch64 Bootlin toolchain, bcmrpi3 kernel
    defconfig, bcm2837 device trees, rootfs bumped to 512M
    - genimage: updated DTB names and kernel image (zImage -> Image)
    - config.txt: add arm_64bit=1
    - build.sh: cross-compile target arm -> aarch64 throughout
    - CLAUDE.md: update cross-compile example to match
    [config.txt, genimage.cfg]
2026-02-21 Clean up Buildroot image: remove QEMU GPU workarounds, add Pi display deps
    Remove the virgl/virtio GPU stack that was added to chase display rendering
    in QEMU (which has an unfixed scanout race and can't actually show it).
    Keep the headless serial-only QEMU target for boot testing.
    Buildroot changes:
    - Replace eudev with devtmpfs (no hotplug needed on a motorbike dash)
    - Remove virgl gallium driver and virtio kernel config fragment
    - Add mesa3d with vc4 driver, libdrm, GBM, and GLES for Pi 3 GPU
    - Mount sysfs in fstab (Mesa needs it to detect the GPU)
    Display app:
    - Use SDL_WINDOW_FULLSCREEN when KMSDRM is the video driver
    - Add startup diagnostics (video driver, renderer, asset load count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
2026-02-21 Implement A/B rootfs update mechanism for atomic USB updates
    4-partition SD card layout (boot, rootfs_a, rootfs_b, data) with
    boot-time USB scan and update script that dd's a new rootfs image
    to the standby partition, flips cmdline.txt, and reboots. Verified
    with successful image build producing correct partition table.
    [genimage.cfg]
2026-03-24 Remove Mega/Gen3 dead code, pi-image directory, and stale references
    - Strip all #ifdef MEGABOARD blocks from firmware (oil pressure/temp
    for Steve's Malta build, Serial2 BLE, Mega pin mappings) and remove
    the GEN4BOARD/MEGABOARD board selection defines — Gen4 is the only
    supported board
    - Delete pi-image/ directory (old hand-configured RetroPie SD card
    config, fully superseded by Buildroot)
    - Fix firmware hex path bug in build.sh update-package (was looking
    for tftdashfirmwareGEN4.hex, actual output is firmware.ino.hex)
    - Update all docs: README, CLAUDE.md, buildroot README, serial
    protocol, signal docs, OTA plan — remove Gen3/Mega/SDL2/armhf/
    RetroPie references
    [config.txt]
2026-03-24 Deduplicate 7 glyph rendering functions into one data-driven renderer
    Replace ~270 lines of near-identical draw_*_string() bodies with a
    single draw_glyph_string() that takes a glyph_font descriptor. Font
    descriptors capture all differences: texture name, sprite atlas coords,
    character set, case sensitivity, spacing, clipping, and per-glyph
    y-offsets. All 86 call sites unchanged via thin wrappers.
2026-03-24 Replace nav symbol strcmp chains with enum and data-driven lookup table
    Replace 28 #define icon constants with a typed nav_icon enum, and
    replace 17 sequential strcmp blocks (~110 lines) with a static
    nav_symbol_entry lookup table. Handles simple icons, driving-side
    variants, and special cases (MEX exit text, PRK/FRY text-only)
    via three inline checks after the table lookup.
2026-03-24 Add navigation controls to simulator
    Symbol dropdown, road/towards text fields, exit number, distance
    (yards/miles), destination distance, and driving-side checkbox.
    Sets InfoMode=3 to activate the nav overlay on the display.
    Includes F5 Navigation preset button.
2026-03-24 Flatten warning badge priority into explicit resolve function
    Replace 4-level nested if/else staircase with a resolve_warning()
    lambda that returns a warning_badge struct. Priority order is now
    a flat list of early-returns: tyre pressure > oil > overheat > fuel.
2026-03-24 Add sensor_feed module with opaque ownership and integration tests
    Standalone module that manages serial/pipe connection, byte framing,
    and message parsing on a background thread. Exposes parsed state
    through const pointers — consumers can read but not write. Uses
    the existing parser module internally (parse_live_message,
    parse_menu_message, parse_nav_message).
    9 integration tests drive the full pipeline through named pipes:
    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
2026-03-25 Fix nav_state to match actual BLE protocol fields
    The parser's nav_state had generic distance/units string fields that
    didn't match the real protocol (confirmed against Danny's original
    UnpackNavMessage from d1eff26). Updated to match the actual wire
    format: yards (int), miles (double), driving_left (int),
    dest_distance (double). Added TYPE_DOUBLE to parser field system.
2026-03-27 Integrate sensor_feed module, removing ~1400 lines of globals and dead code
    Wire sensor_feed into testsdl.cpp as the sole data source. The render
    loop reads state through const pointers (dash->, menu->, nav->)
    refreshed each frame. Deleted: connect_interface, pollInterface,
    unpack_message, unpack_menu_message, unpack_nav_message, choice,
    select, test scenario functions, ~50 global variables, and unused
    includes. Display formats nav distances from numeric fields locally.
    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
2026-03-27 Add menu state controls and presets to simulator
    Menu-specific properties on DashboardState (sprockets, fan temp, themes,
    light levels, etc.) replace hardcoded values in PipeWriter. New Menu
    section in the UI with controls for all fields, 12 preset buttons for
    each menu screen, and F6-F9 key bindings. PipeWriter now sends both
    live and menu messages when MenuState != 0, matching firmware behaviour.
2026-03-27 Add TPMS feed module with frame decoding and tests
    Opaque tpms_feed struct owns serial connection and background thread.
    Supports both Standard (9600 bps, 0xAA 0xA1) and eBay (19200 bps,
    0x55 0xAA) hardware models. Frame decoding functions exposed for unit
    testing — 9 tests covering both protocols, state flags, sensor ID
    mapping, and edge cases. Not yet integrated into testsdl.cpp.
2026-03-27 Integrate TPMS feed module, removing ~440 lines of globals and polling code
    Connection, serial config, frame decoding, and background thread now
    owned by tpms_feed module. Display reads tpms_state via const pointer.
    Removed 25 globals, connect_tpms_interface(), and both polling threads.
2026-03-27 Remove extern C guards from all headers
    No C++ consumers remain — the entire display codebase is C23.
2026-03-27 Rename testsdl.cpp to main.c and binary to dashboard
    Update all references in build.zig, CLAUDE.md, REFACTORING.md, assets
    README, menu module comments, and .gitignore. Rewrite display CLAUDE.md
    to reflect current modular C23 architecture.
2026-03-27 Update buildroot config for testsdl → dashboard rename
    Init script, update script, build script, package recipe, and README
    all updated to reference the new binary name.
2026-03-27 Add comms loss warning badge and simulator pause button
    Display now detects stale or absent serial data and shows a "NO COMMS"
    warning badge — highest priority in the warning chain. sensor_feed
    tracks a timestamp on each live frame; the render loop triggers the
    warning after 1 second of silence or if no connection is established.
    The sensor_feed thread also retries on initial connection failure,
    so the dashboard can start before the simulator.
    Simulator gains a "Pause Comms" toggle that stops pipe writes,
    allowing the warning to be tested without disconnecting.
    New assets: Commsbadge.png and Nocomms.png for all 9 themes.
    [main.c]
2026-03-27 Replace dynamic allocation with static instances in feed modules
    sensor_feed and tpms_feed each have exactly one instance for the
    lifetime of the process. Replace calloc/free with a file-scoped
    static struct, and strdup with a fixed 256-byte path buffer.
    Removes all heap allocation from both modules.
2026-03-27 Harden rendering against corrupt serial data
    Replace all sprintf calls with snprintf to prevent buffer overflows
    from unexpectedly large values. Add bounds check on nav symbol lookup
    to prevent out-of-bounds array access.
    [main.c]
2026-03-27 Log parse failures in sensor_feed instead of silently dropping frames
    Rejected frames, failed live/menu parses, and failed nav parses now
    log to stderr with the frame length and first 50 bytes of content.
    Aids debugging protocol changes and corrupt serial data.
2026-03-28 Integrate flash animation into dashboard_anims module
    Replace flash_count/flash globals with anim_flash (ANIM_LOOP).
    Warning badges, fuel gauge, and coolant temp flashing now read
    anim_is_reversing(&anim_flash) instead of a manual counter.
    Also adds dashboard_anims.h/c with animation instances, info screen
    transition table, and startup rev counter reveal table. anim_tick_all()
    called once per frame in the main loop.
    [main.c]
2026-03-28 Integrate RPM needle animation into dashboard_anims module
    Replace target_rpm_rotation/current_rpm_rotation globals with
    anim_rpm (ANIM_CHASE). anim_set_target() called each frame with
    the current RPM rotation, anim_frame() gives the smoothed value.
    [main.c]
2026-03-28 Integrate info mode transitions into dashboard_anims module
    Replace 170 lines of repeated if-blocks in animate_info_mode() with
    a table-driven approach. Info screens defined in INFO_SCREENS[] table,
    rendered by a generic render_info_screen() helper. ANIM_PING_PONG
    drives the slide-out/slide-in animation for all mode transitions.
    Also adds Info Mode control (0-3) to the simulator UI.
    [main.c]
2026-03-28 Integrate startup animation into dashboard_anims module
    Replace startup_anim_count/startup_done globals and 150 lines of
    imperative startup code with anim_startup (ANIM_ONESHOT, limit=1400).
    Rev counter reveal uses the REV_REVEAL[] table — a loop replaces 13
    repeated if-blocks in both dashboard_startup() and draw_dashboard().
    The 13 individual rect globals are removed.
    Background fade runs on all themes (invisible on dark ones), removing
    the theme-conditional skip. Panel slide positions derived from
    anim_frame() instead of manual counter arithmetic.
    [main.c]
2026-03-28 Extract rendering code from main.c into focused modules
    main.c drops from 2200 to 332 lines — now just SDL init, event loop,
    and frame dispatch.
    New modules:
    - draw.h/c (432 lines): shared rendering state, sprite atlas tables,
    glyph font system, and all drawing primitives
    - draw_dashboard.h/c (857 lines): startup animation, dashboard
    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
2026-03-28 Clean up main.c — extract init/loop helpers, remove dead code
    main.c drops from 332 to 162 lines. main() is now a clear sequence:
    init_feeds, init_sdl, init_assets, then a loop of tick/refresh/
    handle_events/render/update_warnings.
    Removed: 70-line legacy comment block, unused globals (test_counter,
    reverse, ncount, g_down_arrow_x, g_up_arrow_x), unused functions
    (cycle_digit, file_exists), unused includes (fcntl, termios, errno,
    pthread), and commented-out code.
    [main.c]
2026-03-28 Extract declarative warnings module
    Warning conditions are now a priority-ordered table in warnings.c.
    Each entry has a condition function, badge texture, and flash texture
    function. Adding a new warning is just adding a row to the table.
    The module owns engine-running hysteresis and comms staleness state.
    draw_dashboard.c queries warnings_active() for what to render.
    main.c just calls warnings_update() once per frame.
    Removes resolve_warning(), warning_badge typedef, and the scattered
    fuelwarning/overheatwarning/enginerunning/comms_stale globals.
    [main.c]
2026-03-28 Add warnings module test suite (18 tests)
    Tests all five warning conditions, priority ordering, engine running
    hysteresis, cancellation, and the dynamic tyre pressure flash texture.
    No SDL dependency — uses a stub for get_num_fuel_bars.
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2026-03-28 Eliminate init-time mutable state and simplify main.c to 45 lines
    Replace draw_dashboard_init_rects() with compile-time const
    initialisers for all rects, oil lookup tables, and speedometer
    digit positions. The init function is deleted entirely.
    str_trip_time and str_time initialised at declaration instead of
    from main.c. spd_digit rects replaced with a const position table
    and local rects in draw_speed_digit().
    main.c no longer includes draw_dashboard.h, string.h, or stdio.h.
    [main.c]
2026-03-28 Replace per-frame draw_update() with one-time draw_set_state()
    Sensor state pointers are set once after feeds start — they never
    change since the feed modules return stable pointers to internal
    state. Theme change detection moved into draw_frame().
    [main.c]
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2026-03-28 Fix review findings: bugs, architecture, and test coverage
    Bugs:
    - Fix integer division precision loss in get_litres_remaining() —
    12 instances of (1000/N) now use floating-point division
    - Remove unreachable return in get_diff()
    - Change main() signature to int main(void)
    Architecture:
    - Remove SDL dependency from dashboard_anims.h — replace SDL_FRect
    with plain floats in info_screen and rev_reveal_entry structs
    - Make info_current_mode static with accessor functions
    - Add internal interface comment to draw.h
    Tests (85 total, up from 80):
    - Add test_helpers.h with shared assertion macros across all suites
    - Parser: field overflow test with 253-char nav string
    - Sensor feed: bounda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
    [main.c]

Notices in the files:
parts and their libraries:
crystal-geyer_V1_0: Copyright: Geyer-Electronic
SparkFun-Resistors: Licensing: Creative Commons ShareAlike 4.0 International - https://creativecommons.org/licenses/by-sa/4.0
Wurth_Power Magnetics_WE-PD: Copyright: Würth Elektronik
